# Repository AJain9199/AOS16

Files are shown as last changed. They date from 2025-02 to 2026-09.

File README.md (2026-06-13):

<!-- Improved compatibility of back to top link: See: https://github.com/othneildrew/Best-README-Template/pull/73 -->

<!--
*** Thanks for checking out the Best-README-Template. If you have a suggestion
*** that would make this better, please fork the repo and create a pull request
*** or simply open an issue with the tag "enhancement".
*** Don't forget to give the project a star!
*** Thanks again! Now go create something AMAZING! :D
-->

<!-- PROJECT SHIELDS -->
<!--
*** I'm using markdown "reference style" links for readability.
*** Reference links are enclosed in brackets [ ] instead of parentheses ( ).
*** See the bottom of this document for the declaration of the reference variables
*** for contributors-url, forks-url, etc. This is an optional, concise syntax you may use.
*** https://www.markdownguide.org/basic-syntax/#reference-style-links
-->

<!-- PROJECT LOGO -->
<br />
<div align="center">
    <a href="https://github.com/github_username/repo_name">
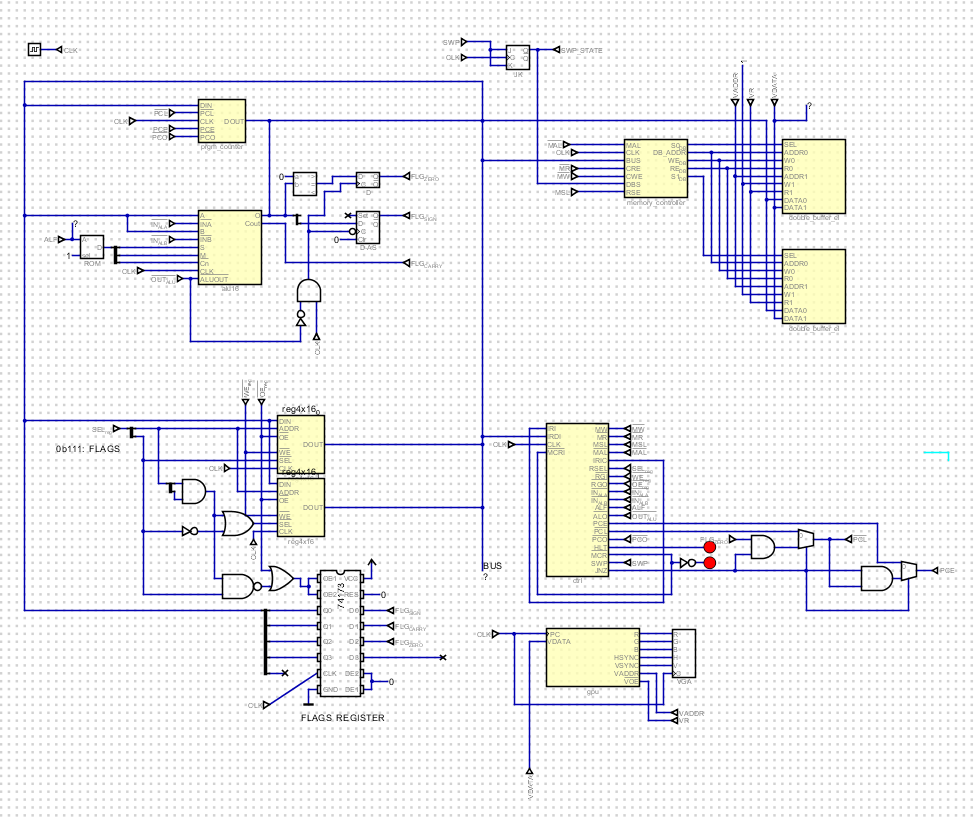
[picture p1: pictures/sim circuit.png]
    
  </a>
    <h1 align="center">AOS16</h1>
  <p align="center">
    A self-made 16-bit computer.
  </p>
</div>

<!-- TABLE OF CONTENTS -->
<details>
  <summary>Table of Contents</summary>
  <ol>
    <li>
      <a href="#about-the-project">About The Project</a>
    </li>
    <li><a href="#pictures">Pictures</a></li>
    <li><a href="#technical-details">Technical Details</a></li>
    <li><a href="#directory-structure">Directory Structure</a></li>
    <li><a href="#to-do">To-Do</a></li>
    <li><a href="#acknowledgments">Acknowledgments</a></li>
  </ol>
</details>

<!-- ABOUT THE PROJECT -->

## About The Project

AOS16 is a self-made 16-bit Reduced Instruction Set Computer (RISC) on PCBs, complete with a homebrew GPU for screen output. It is fully planned, designed and fabricated from scratch. A Turing-complete, Harvard-style computer with a completely custom architecture, at a blistering fast 10MHz.

The project is divided into smaller subsytems on PCBs, designed to interconnect via a central bus.

### Features
- 16-bit address and data buses
- Hardware double buffering with parallel CPU and GPU operation
- 10 MHz clock
- 6 general-purpose registers, a stack pointer and a flags register
- 65 Kb of general purpose RAM
- 131 Kb of framebuffer (double buffered, so 65Kb usable)
- 131 Kb of program memory

### Why?

This project was a learning effort for me. I started this project wanting to learn more about computer architectures and gain hands-on experience with electrical engineering. Also, building a computer, from scratch, is the coolest project I've seen around. Some inspiration from amazing engineers including Ben Eater and jdh were more than enough to convince me to try my hand at this project.

### How's it different?

Most homebrew computers on the internet are 8-bit computers built on breadboards.  AOS16 is novel in its capabilities, being a 16-bit computer built on PCBs with a much higher clock speed, with display support directly integrated. 

<p align="right">(<a href="#readme-top">back to top</a>)</p>

## Pictures

<!-- The animated GIFs will not be visible in the PDF! Please visit the repository on [Github](https://github.com/AJain9199/AOS16). -->

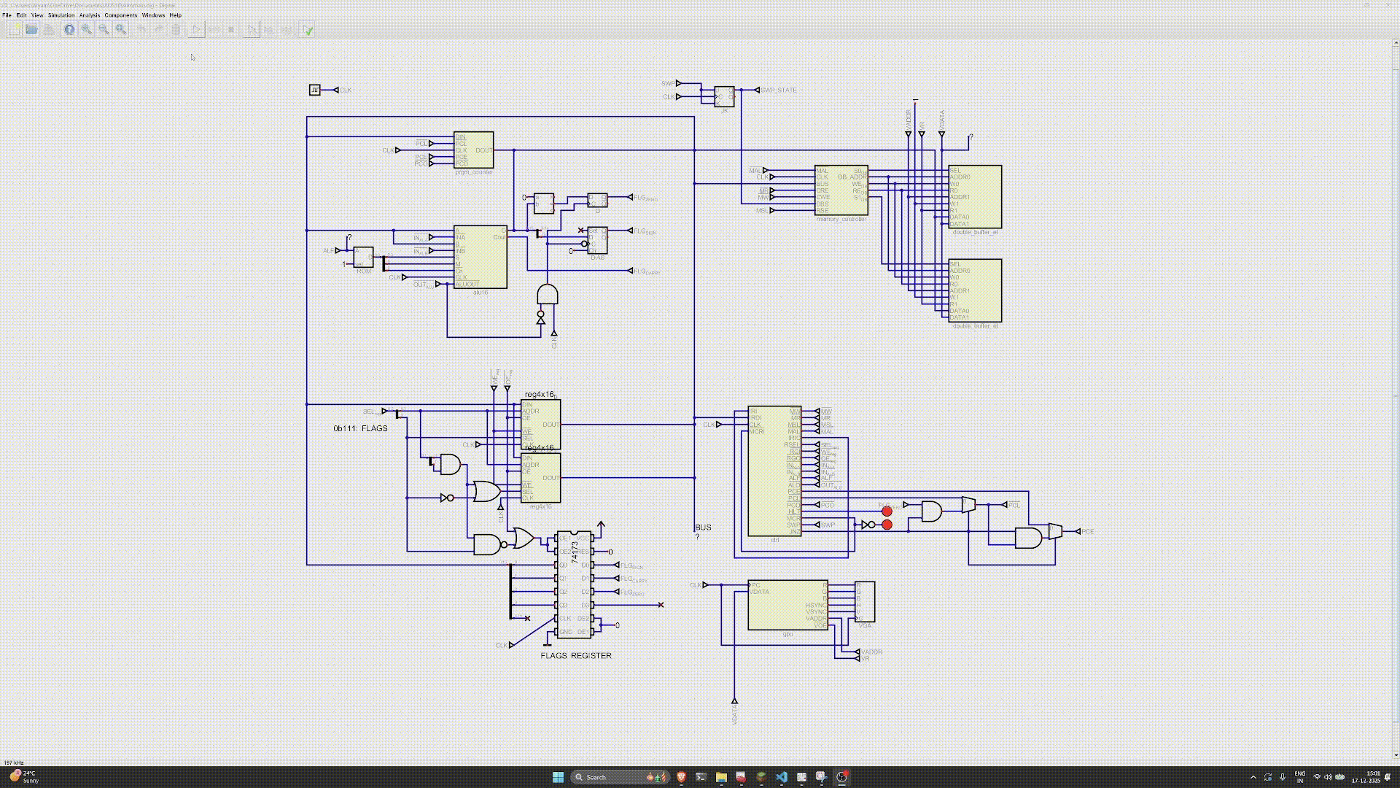
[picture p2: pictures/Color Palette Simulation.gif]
Simulation of Color Palette on Screen


<h2 align="center">
A simulation of the computer in Digital displaying the color palette on the screen
</h2>

<br>

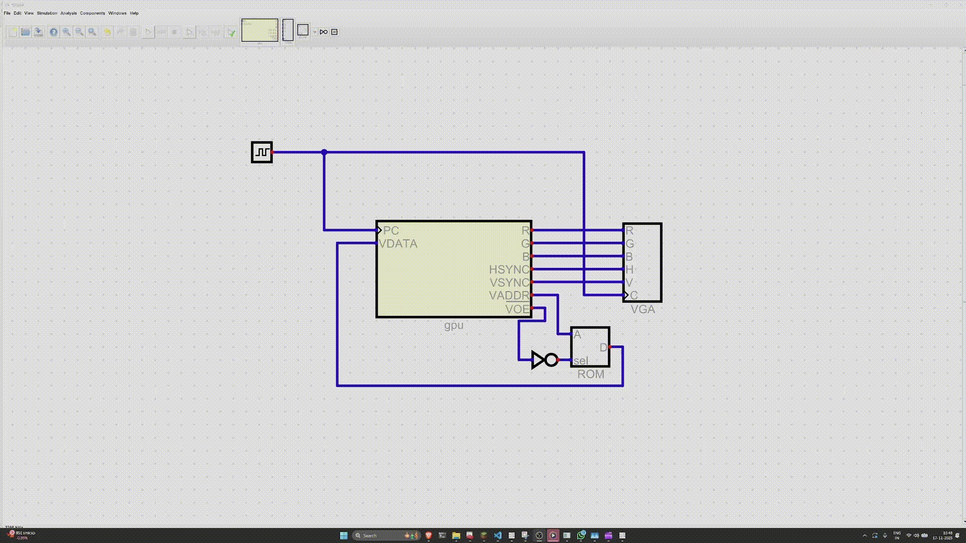
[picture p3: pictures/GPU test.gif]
A GPU Test


<h2 align="center">
    GPU displaying the pillars of creation
</h2>

<br>

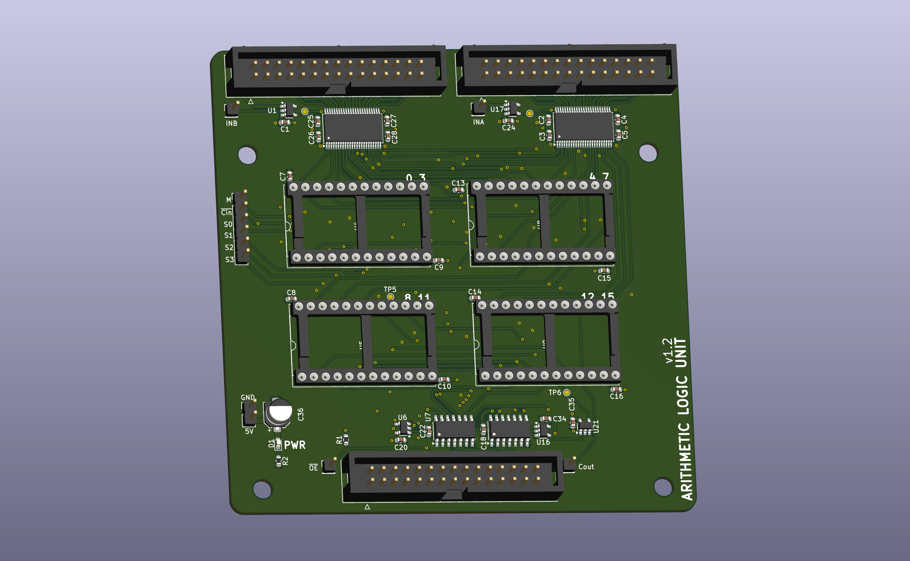
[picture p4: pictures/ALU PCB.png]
ALU PCB


<h2 align="center">
    The Arithmetic Logic Unit in KiCAD
</h2>

<br>

Logic Simulation in Digital

<h2 align="center">
    The logic simulation in Digital.
</h2>

<br>

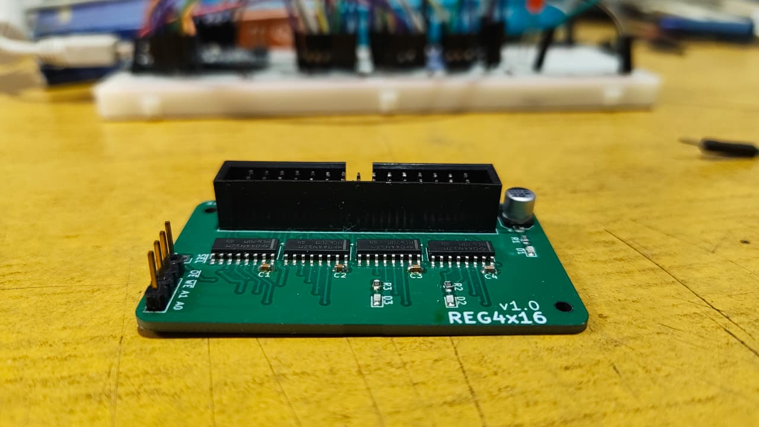
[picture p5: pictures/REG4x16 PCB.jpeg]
Fabricated Reg4x16 PCB


<h2 align="center">
    The Reg4x16 PCB 
</h2>

<br>

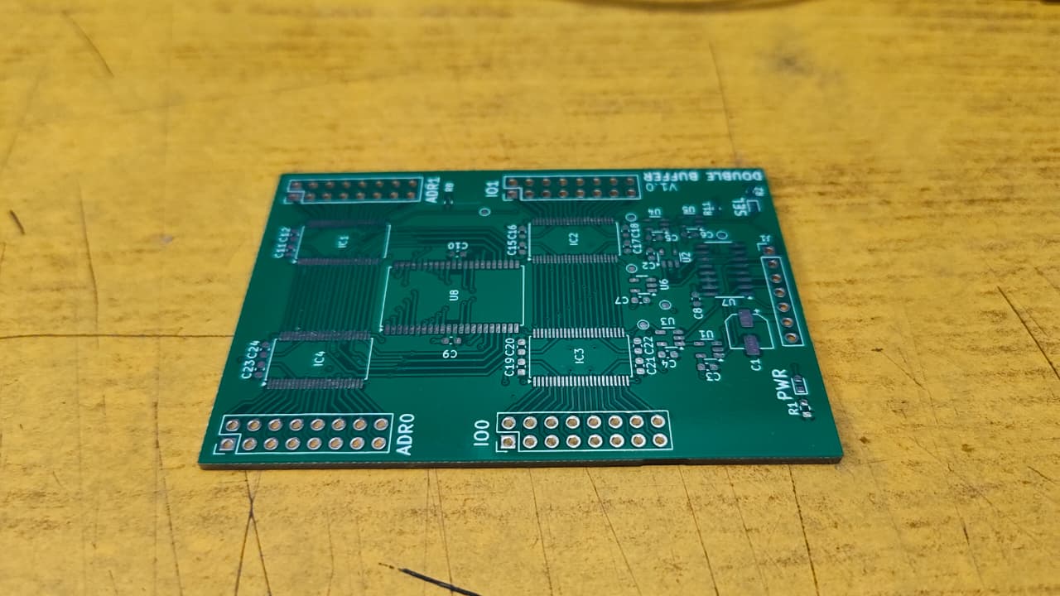
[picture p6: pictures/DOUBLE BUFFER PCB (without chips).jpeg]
Fabricated Double Buffer PCB


<h2 align="center">
    The Double Buffer PCB
</h2>

<br>

<p align="right">(<a href="#readme-top">back to top</a>)</p>

## Technical Details

Details about the design decisions, design of the instruction word, etc. can be found in the [Design Doc](AOS-16%20Design.md).

## Directory Structure

- assembler: Contains the source code for the AOS16 assembler
- sim: Logic simulation files written for Digital
- microcode: Microcode implementations written in MiLa
- tests: some basic tests for ICs and the simulation
- common: basic KiCAD schematics (registers, transceivers) which are shared across subsystems

Each of the remaining folders represents a subsystem, built on a separate PCB. Each folder will contain a KiCAD schematic and PCB file.

## To-do

Main Phases of the project:

-   [x] Finalize project parameters and design goals
-   [ ] Hardware:
    -   [x] Logic Simulation and Design
    -   [ ] PCB Design
    -   [ ] PCB Fabrication & integration
-   [x] Software:
    -   [x] Microcode (with [MiLa](https://github.com/AJain9199/MiLa))
    -   [x] Assembly language design
    -   [x] Assembler
    -   [x] ROM programming software

<br>

| Component / Phase | Logic Simulation | PCB Design | Fabrication and Integration |
| --- | --- | --- | --- |
| Double Buffer | ✅ | ✅ | ✅ |
| Memory Controller | ✅ | ✅ | ✅ |
| ALU | ✅ | ✅ | ✅ |
| Registers | ✅ | ✅ | ✅ |
| Control Unit | ✅ | ✅ |  ✅ |
| Program Counter | ✅ | ✅ |  ☐ |
| GPU | ✅ | ✅ | ☐ |
| Main Data Bus | ✅ | ✅ | ☐ |
| **Phase Completed** | ✅ | ✅ | ☐ |

<p align="right">(<a href="#readme-top">back to top</a>)</p>

<!-- ACKNOWLEDGMENTS -->
## Acknowledgments

-   [Ben Eater](https://www.youtube.com/@BenEater) for his excellent series on the breadboard computer
-   [jdh](https://www.youtube.com/@jdh) for the inspiration
-   The Elements of Computing Systems and the accompanying [Nand2Tetris](https://www.nand2tetris.org/) course by Shimon Schocken and Noam Nisan
-   [r/homebrewcomputer](https://www.reddit.com/r/homebrewcomputer/) and [r/PrintedCircuitBoard](https://www.reddit.com/r/PrintedCircuitBoard/) commmunities for PCB reviews and design checks
-   [Digital](https://github.com/hneemann/Digital), the logic simulator

<p align="right">(<a href="#readme-top">back to top</a>)</p>

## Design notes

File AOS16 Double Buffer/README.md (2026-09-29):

# Double Buffer
The double buffer is one of the most complicated PCBs in the project. It serves the important function of facilitating data transfer between the CPU and GPU.

```mermaid
flowchart LR
    ADDR0[\"ADDR0"\]
    IO0[\"IO0"\]
    buf1["Buffer"]
    buf2{{"Transceiver"}}
    sram["SRAM"]
    ADDR1[/"ADDR1"/]
    IO1[/"IO1"/]
    buf3["Buffer"]
    buf4{{"Transceiver"}}
    ctrl["`Control Circuit`"]
    nr0(("nR0"))
    nw0(("nW0"))
    nr1(("nR1"))
    nw1(("nW1"))
    swp(("SWP"))
    ADDR0 --> buf1
    IO0 --> buf2
    buf1 --> sram
    buf2 --> sram
    ADDR1 --> buf3
    IO1 --> buf4
    buf3 --> sram
    buf4 --> sram
    nr0 --> ctrl
    nw0 --> ctrl
    nr1 --> ctrl
    nw1 --> ctrl
    swp --> ctrl
    ctrl -->|"direction, output enable"| buf2
    ctrl -->|"direction, output enable"| buf4
    ctrl -->|"output enable"| buf1
    ctrl -->|"output enable"| buf3
    linkStyle 14 stroke:#aaaaaa,color:#888888
    %% mermaid-flow:pos ADDR0=292,326 IO0=295,462 buf1=482,329 buf2=482,462 sram=693,404 ADDR1=1056,323 IO1=1059,465 buf3=887,323 buf4=884,465 ctrl=689,899 nr0=302,1107 nw0=302,977 nr1=302,847 nw1=302,717 swp=302,587
```

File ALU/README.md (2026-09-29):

# Arithmetic Logic Unit
The Arithmetic Logic Unit is one of the the first PCBs I designed and built as part of the project. It is essentially a wrapper for the 74LS181 ICs, 4 of them handling each of the 4 nibbles, with additional circuitry to manage the IO and carry generation for each of the 4 chips.

ALU PCB

```mermaid
flowchart LR
	porta@{ shape: lean-r, label: "PORT A"}
	latcha["`Latch A`"]
	porta --> latcha
	ina((INA))
	ina --> latcha
	
	portb@{ shape: lean-r, label: "PORT B"}
	latchb["`Latch B`"]
	portb --> latchb
	inb((INB))
	inb --> latchb
	
	subgraph alu [Arithmetic Unit]
		aluchip1@{ shape: subproc, label: "74LS181 A" }
		aluchip2@{ shape: subproc, label: "74LS181 B" }
		aluchip3@{ shape: subproc, label: "74LS181 C" }
		aluchip4@{ shape: subproc, label: "74LS181 D" }
		
		carrygen["`Carry Generator`"]
		
		carrygen --> aluchip1
		carrygen --> aluchip2
		carrygen --> aluchip3
		carrygen --> aluchip4
	end
	
	latcha --> alu
	latchb --> alu
	
	buffer@{shape: tri, label: "Tri-State Buffer"}
	noe((nOE))
	noe --> buffer
	
	alu --> buffer --> outport
	carryout((nCo))
	alu --> carryout
	
	alus(["`S[0..3]`"]) --> alu
	m((M)) --> alu
	cin((nCin)) --> alu
	
	outport@{ shape: lean-r, label: "OUTPUT"}
```

## Carry Generation

Since each 74LS181 chip only handles 4 bits, 4 of these chips need to be used together. Instead of cascading them using the built-in carry outputs, I used full look-ahead carry generation which is more than 2x faster ([sn54s181](sn54s181.pdf)) (realistically both are fine at the speeds this works at, this is simply future/idiot proofing) But I couldn't find the carry generation chip, the 182, so I replicated the internal circuit using discrete (A)HCT gates ([sn54s182](sn54s182.pdf)).

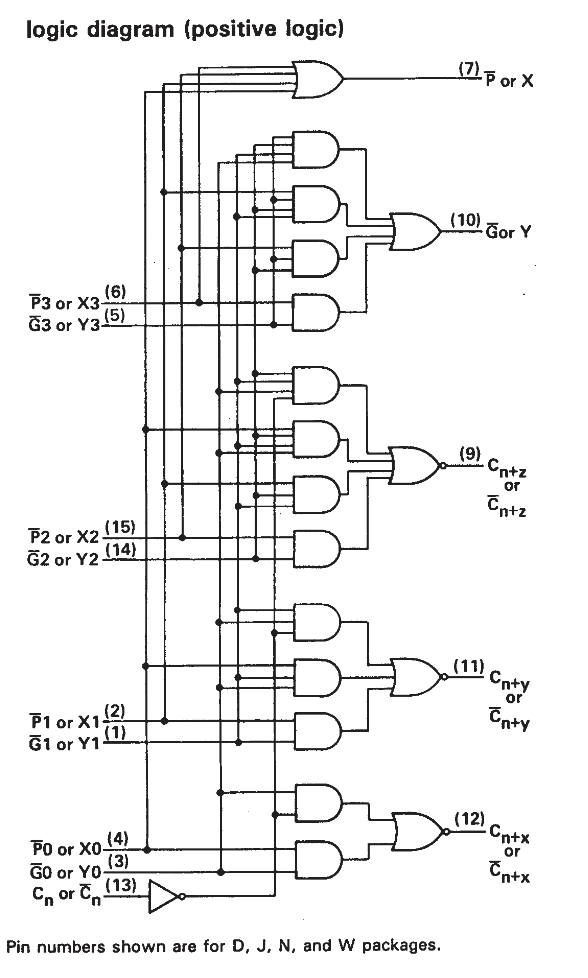
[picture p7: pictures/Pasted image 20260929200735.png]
Circuit diagram


Since I wasn't sure if this will work, I added test pads on the cascade carry outputs and inputs so they could be used as a contingency.

## Latches
The 181s need both A and B inputs driven at the same time to function correctly. Since they ultimately need to be driven by the same bus, the inputs are latched using separate signals which drive the physical inputs. I considered adding a second bus only to drive port B, but the added complexity was not worth the benefit of saving 1-2 microcode instructions and 2 control signals.

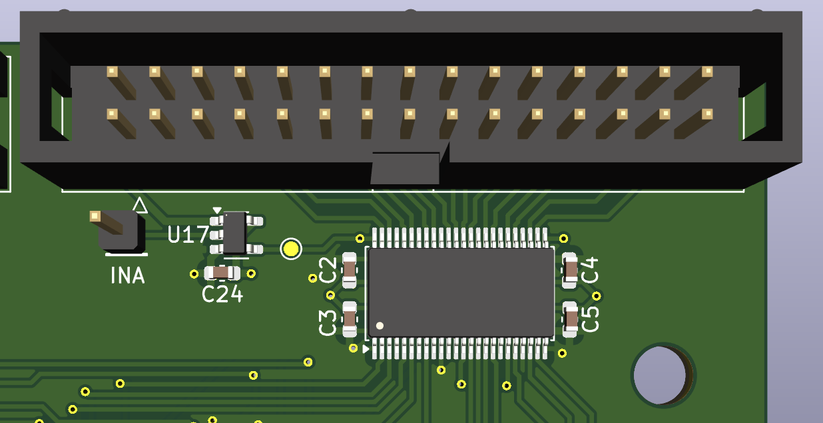
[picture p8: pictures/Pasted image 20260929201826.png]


Inputs are latched at the rising edge. The AHCT16374's ([sn74ahct16374](sn74ahct16374.pdf)) are asynchronous, so the latching input is and'ed with the clock to make them "synchronous."

## Iterations
- v1.0: The control signals on the 16374 were routed wrong due to a schematic symbol mismatch
- v1.1: The 16374 was routed wrong (again)
- v1.2: Final

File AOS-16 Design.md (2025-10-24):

# AOS-16

## Features

-   16-bit data and address buses
-   Harvard architecture
-   GPU hardware double bufferring
-   Memory Mapped IO

## Instruction

-   5-bit Opcode for a total of 32 distinct instructions
-   Direction Bit: Determines whether contents move from operand 1 to 2 (0) or operand 2 to 1 (1)
-   Reg: 3-bit register select
-   M/C/Reg: 2 bits to control whether operand is an immediate, immediate pointer, register pointer or simply a register, for a total of 5 bits.
-   If the 'C' flag is set, the instruction must be 4 bytes long. Other instructions are 2 bytes long.

### Instruction Set

-   00000: ADD reg/m, m/imm16/reg
-   00001: SUB reg/m, m/imm16/reg
-   00010: AND reg/m, m/imm16/reg
-   00011: NAND reg/m, m/imm16/reg
-   00100: OR reg/m, m/imm16/reg
-   00101: NOR reg/m, m/imm16/reg
-   00110: XOR reg/m, m/imm16/reg
-   00111: NEG reg/m, m/imm16/reg
-   01000: NOT reg/m, m/imm16/reg
-   01001: SHL reg/m
-   01010: INC reg/m
-   01011: DEC reg/m
-   01100: CMP reg/m, m/imm16/reg
-   01101: MOV reg/m, m/imm16/reg
-   01110: PUSH m/imm16/reg
-   01111: POP m/reg
-   10000: SWP
-   10001: JMP imm16/reg
-   10010: JNZ imm16/reg
-   10011: JEQ imm16/reg
-   10100: JLT imm16/reg
-   10101: JLE imm16/reg
-   10110: JGT imm16/reg
-   10111: JGE imm16/reg
-   11000: HLT
-   11001: CALL imm16/reg/m
-   11010: RET
-   11011: INT imm4
-   11100: IRET
-   11101 - 11110: UNALLOCATED
-   11111: NOP (Data is all high in EEPROM upon erase)

## Registers

-   000: AX
-   001: BX
-   010: CX
-   011: DX
-   100: EX
-   101: FX
-   110: SP: Stack Pointer
-   111: STATUS

### STATUS REGISTER

The bits in the status register, from LSB to MSB:

-   0: GPU READY
-   1: ZF
-   2: CF
-   3: SF
-   4-15: unallocated

## Memory Map

0x0000...0x7FF7: GP RAM
0x7FF8...0x7FFF: MEMORY MAPPED IO
0x8FFF...0xFFFF: FRAMEBUFFER

## Control Word

-   0: MI: Memory Write
-   1: MO: Memory Out
-   2: MSL: Memory Select (0 for RAM, 1 for ROM)
-   3: MAI: Memory Address In
-   4: IRI: Instruction Register In
-   5...7: RSA[3]: Register Select for Bus A (see REGISTERS)
-   8: RGI: Register In
-   9: RGO: Register Out
-   10: AAI: ALU A In
-   11: ABI: ALU B In
-   12...15: ALF[4]: ALU Opcode
-   16: /ALO: ALU Out
-   17: PCE: Program Counter Enable
-   18: /PCL: Program Counter Load/Jump
-   19: PCO: Program Counter Out
-   20: HLT: Global Halt
-   21: MCR: Microcode Reset
-   22: SWAP: Swap the double buffer selection

## Application Binary Interface (ABI)
Functions are called using the `call` instruction. The current instruction pointer is pushed to the stack. Arguments to the function are pushed onto the stack in order. Results are placed in the 'dx' register.

`ret` restores the instruction pointer to the last word on the stack.

## GPU
VGA Timing Mode: VESA 1280x1024 @60Hz\
Resolution: 160x128 (5:4 aspect ratio)\
Clock: 13.5MHz

### VGA Timing
Horizontal Timing

| Scanline Part | Pixels | Pixel Counter |
|---|---| --- |
| Visible Area  | 160 | 160 (0b10100000) |
| Front porch | 6 | 166 (0b10100110) |
| Sync Pulse | 14 | 180 (0b10110100) |
| Back porch | 31 | 211 (0b11010011) |
| Whole Line | 211 | |

 Vertical Timing (Every pixel is repeated 8 times in vertical direction to achieve 128 lines)

| Frame part | Lines | Line Counter | 
| --- | ----- | --- |
| Visible Area | 1024 | 1024 (0b0100 0000 0000) |
| Front porch | 1 | 1025 (0b0100 0000 0001) |
| Sync Pulse | 3| 1028 (0b0100 0000 0100)|
| Back Porch | 38 | 1066 (0b0100 0010 1010) |

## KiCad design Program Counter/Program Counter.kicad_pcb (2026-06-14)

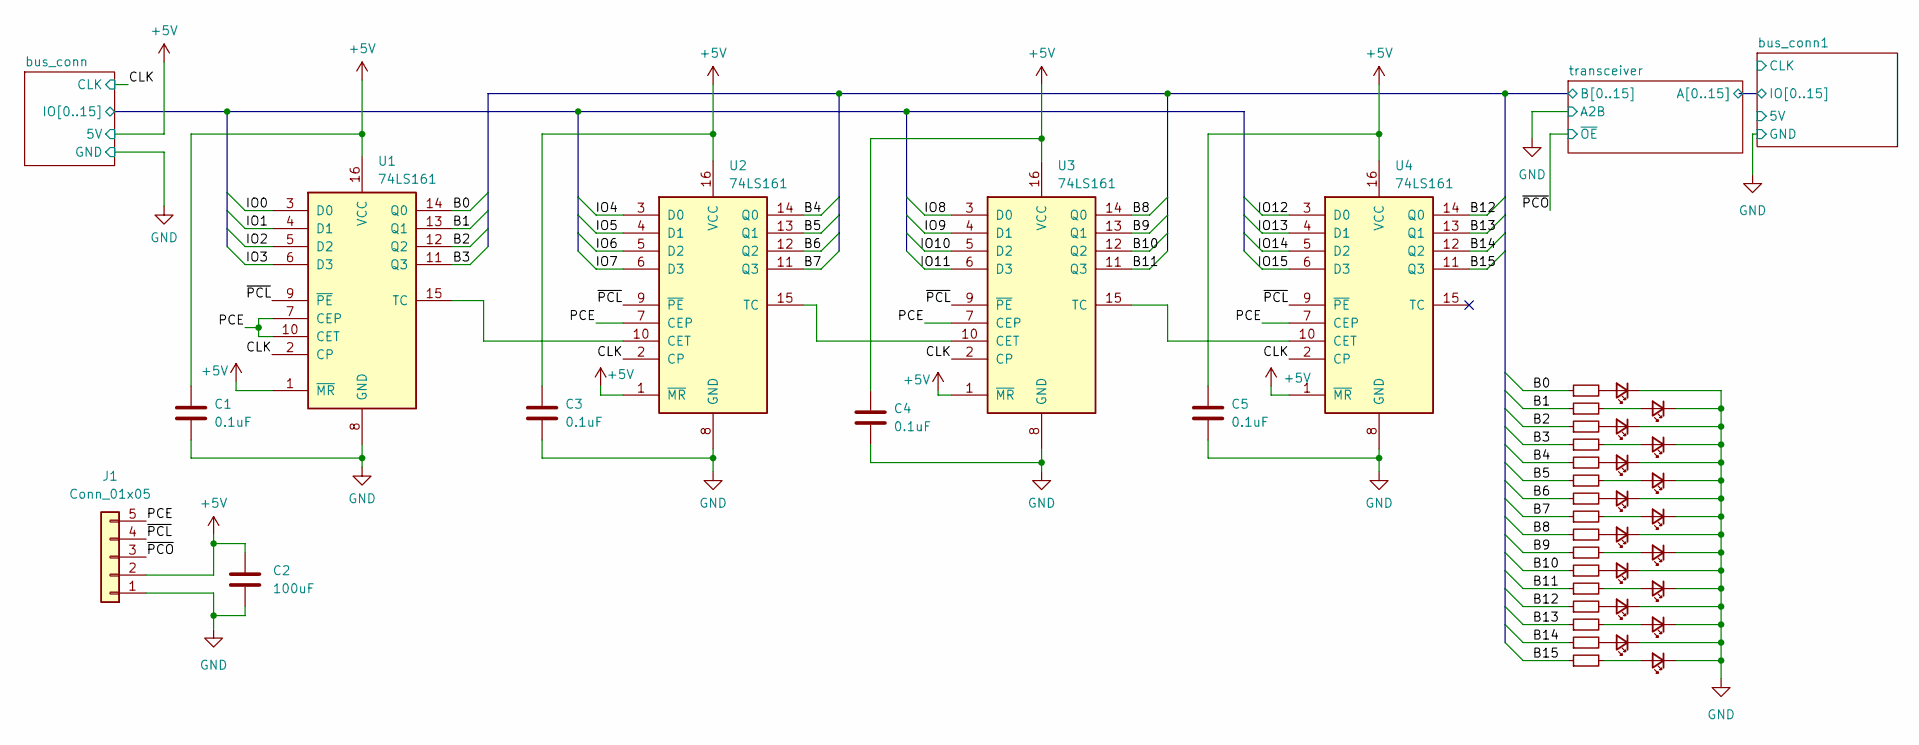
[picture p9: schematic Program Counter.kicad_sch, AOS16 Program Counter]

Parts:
C1, C3, C4, C5: 0.1uF; C_0603_1608Metric
C2: 100uF; CP_Elec_5x5.3
D1, D2, D3, D4, D5, D6, D7, D8, D9, D10, D11, D12, D13, D14, D15, D16: LED_Small; LED_0603_1608Metric
J1: Conn_01x05; PinHeader_1x05_P2.54mm_Vertical
R2, R3, R4, R5, R6, R7, R8, R9, R10, R11, R12, R13, R14, R15, R16, R17: 220; R_0603_1608Metric
U1, U2, U3, U4: 74LS161; SOIC-16_4.55x10.3mm_P1.27mm

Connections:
/CLK: U1.2 (CP), U2.2 (CP), U3.2 (CP), U4.2 (CP); also elsewhere on the board
/PCE: J1.5, U1.7 (CEP), U1.10 (CET), U2.7 (CEP), U3.7 (CEP), U4.7 (CEP)
/bus_conn/IO0: U1.3 (D0); also elsewhere on the board
/bus_conn/IO1: U1.4 (D1); also elsewhere on the board
/bus_conn/IO2: U1.5 (D2); also elsewhere on the board
/bus_conn/IO3: U1.6 (D3); also elsewhere on the board
/bus_conn/IO4: U2.3 (D0); also elsewhere on the board
/bus_conn/IO5: U2.4 (D1); also elsewhere on the board
/bus_conn/IO6: U2.5 (D2); also elsewhere on the board
/bus_conn/IO7: U2.6 (D3); also elsewhere on the board
/bus_conn/IO8: U3.3 (D0); also elsewhere on the board
/bus_conn/IO9: U3.4 (D1); also elsewhere on the board
/bus_conn/IO10: U3.5 (D2); also elsewhere on the board
/bus_conn/IO11: U3.6 (D3); also elsewhere on the board
/bus_conn/IO12: U4.3 (D0); also elsewhere on the board
/bus_conn/IO13: U4.4 (D1); also elsewhere on the board
/bus_conn/IO14: U4.5 (D2); also elsewhere on the board
/bus_conn/IO15: U4.6 (D3); also elsewhere on the board
/transceiver/B0: R2.1, U1.14 (Q0); also elsewhere on the board
/transceiver/B1: R3.1, U1.13 (Q1); also elsewhere on the board
/transceiver/B2: R4.1, U1.12 (Q2); also elsewhere on the board
/transceiver/B3: R5.1, U1.11 (Q3); also elsewhere on the board
/transceiver/B4: R6.1, U2.14 (Q0); also elsewhere on the board
/transceiver/B5: R7.1, U2.13 (Q1); also elsewhere on the board
/transceiver/B7: R9.1, U2.11 (Q3); also elsewhere on the board
/transceiver/B8: R10.1, U3.14 (Q0); also elsewhere on the board
/transceiver/B9: R11.1, U3.13 (Q1); also elsewhere on the board
/transceiver/B10: R12.1, U3.12 (Q2); also elsewhere on the board
/transceiver/B11: R13.1, U3.11 (Q3); also elsewhere on the board
/transceiver/B12: R14.1, U4.14 (Q0); also elsewhere on the board
/transceiver/B13: R15.1, U4.13 (Q1); also elsewhere on the board
/transceiver/B14: R16.1, U4.12 (Q2); also elsewhere on the board
/transceiver/B15: R17.1, U4.11 (Q3); also elsewhere on the board
/~PCL: J1.4, U1.9 (~PE), U2.9 (~PE), U3.9 (~PE), U4.9 (~PE)
GND: C1.2, C2.2, C3.2, C4.2, C5.2, D1.1 (K), D2.1 (K), D3.1 (K), D4.1 (K), D5.1 (K), D6.1 (K), D7.1 (K), D8.1 (K), D9.1 (K), D10.1 (K), D11.1 (K), D12.1 (K), D13.1 (K), D14.1 (K), D15.1 (K), D16.1 (K), J1.1, U1.8 (GND), U2.8 (GND), U3.8 (GND), U4.8 (GND); also elsewhere on the board
unnamed: D1.2 (A), R2.2
unnamed: D2.2 (A), R4.2
unnamed: D3.2 (A), R6.2
unnamed: D5.2 (A), R10.2
unnamed: D6.2 (A), R12.2
unnamed: D7.2 (A), R14.2
unnamed: D8.2 (A), R16.2
unnamed: D9.2 (A), R3.2
unnamed: D10.2 (A), R5.2
unnamed: D11.2 (A), R7.2
unnamed: D12.2 (A), R9.2
unnamed: D13.2 (A), R11.2
unnamed: D14.2 (A), R13.2
unnamed: D15.2 (A), R15.2
unnamed: D16.2 (A), R17.2
unnamed: U1.15 (TC), U2.10 (CET)
unnamed: U2.15 (TC), U3.10 (CET)
unnamed: U3.15 (TC), U4.10 (CET)

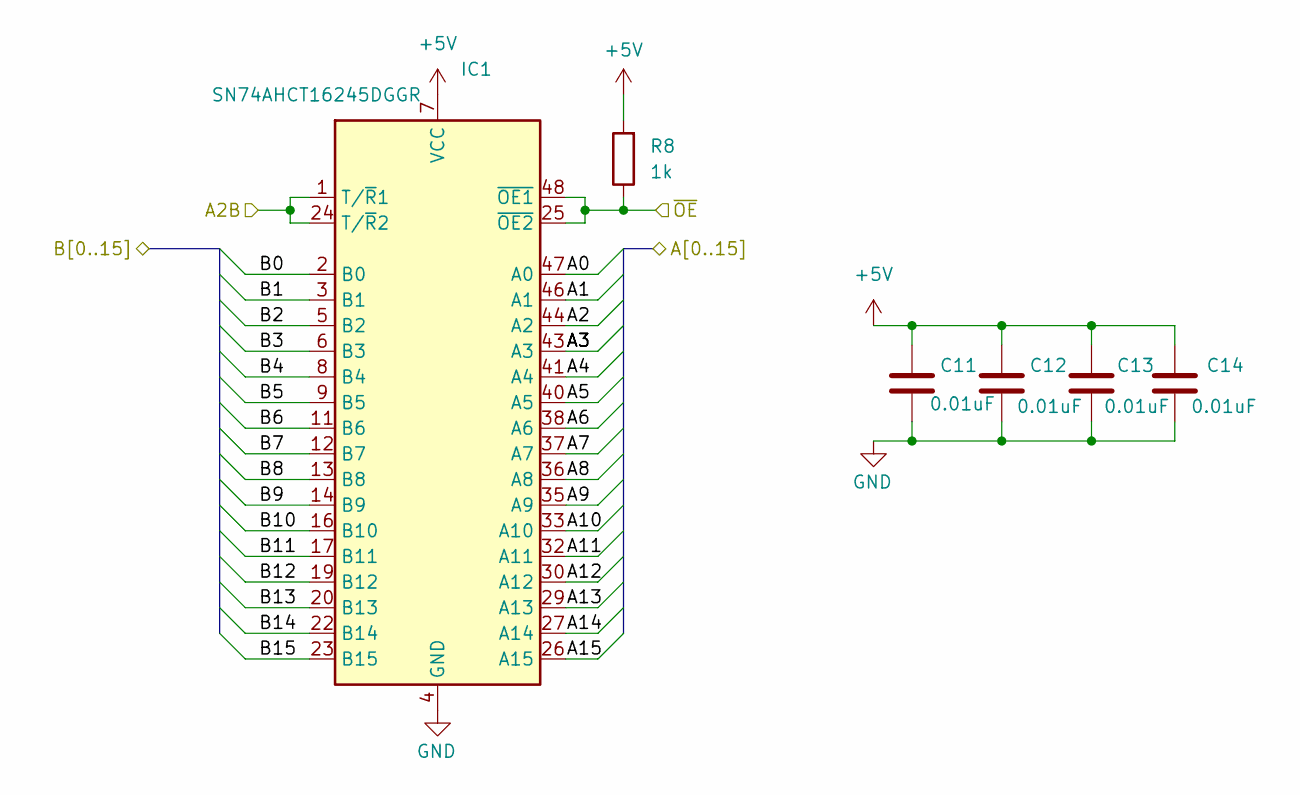
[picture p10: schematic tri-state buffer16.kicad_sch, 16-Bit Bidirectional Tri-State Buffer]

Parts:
C11, C12, C13, C14: 0.01uF; C_0603_1608Metric
IC1: SN74AHCT16245DGGR; TSSOP-48_6.1x12.5mm_P0.5mm
R8: 1k; R_0603_1608Metric

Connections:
/bus_conn1/IO0: IC1.47 (A0); also elsewhere on the board
/bus_conn1/IO1: IC1.46 (A1); also elsewhere on the board
/bus_conn1/IO2: IC1.44 (A2); also elsewhere on the board
/bus_conn1/IO3: IC1.43 (A3); also elsewhere on the board
/bus_conn1/IO4: IC1.41 (A4); also elsewhere on the board
/bus_conn1/IO5: IC1.40 (A5); also elsewhere on the board
/bus_conn1/IO6: IC1.38 (A6); also elsewhere on the board
/bus_conn1/IO7: IC1.37 (A7); also elsewhere on the board
/bus_conn1/IO8: IC1.36 (A8); also elsewhere on the board
/bus_conn1/IO9: IC1.35 (A9); also elsewhere on the board
/bus_conn1/IO10: IC1.33 (A10); also elsewhere on the board
/bus_conn1/IO11: IC1.32 (A11); also elsewhere on the board
/bus_conn1/IO12: IC1.30 (A12); also elsewhere on the board
/bus_conn1/IO13: IC1.29 (A13); also elsewhere on the board
/bus_conn1/IO14: IC1.27 (A14); also elsewhere on the board
/bus_conn1/IO15: IC1.26 (A15); also elsewhere on the board
/transceiver/B0: IC1.2 (B0); also elsewhere on the board
/transceiver/B1: IC1.3 (B1); also elsewhere on the board
/transceiver/B2: IC1.5 (B2); also elsewhere on the board
/transceiver/B3: IC1.6 (B3); also elsewhere on the board
/transceiver/B4: IC1.8 (B4); also elsewhere on the board
/transceiver/B5: IC1.9 (B5); also elsewhere on the board
/transceiver/B7: IC1.12 (B7); also elsewhere on the board
/transceiver/B8: IC1.13 (B8); also elsewhere on the board
/transceiver/B9: IC1.14 (B9); also elsewhere on the board
/transceiver/B10: IC1.16 (B10); also elsewhere on the board
/transceiver/B11: IC1.17 (B11); also elsewhere on the board
/transceiver/B12: IC1.19 (B12); also elsewhere on the board
/transceiver/B13: IC1.20 (B13); also elsewhere on the board
/transceiver/B14: IC1.22 (B14); also elsewhere on the board
/transceiver/B15: IC1.23 (B15); also elsewhere on the board
GND: C11.2, C12.2, C13.2, C14.2, IC1.1 (T/~R1), IC1.4 (GND), IC1.10 (GND), IC1.15 (GND), IC1.21 (GND), IC1.24 (T/~R2), IC1.28 (GND), IC1.34 (GND), IC1.39 (GND), IC1.45 (GND); also elsewhere on the board

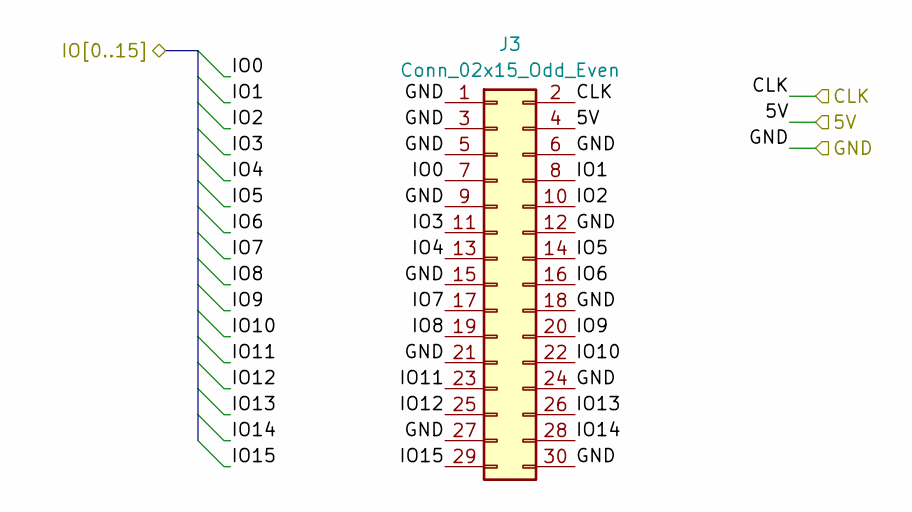
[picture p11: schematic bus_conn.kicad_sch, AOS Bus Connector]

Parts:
J3: Conn_02x15_Odd_Even; IDC-Header_2x15_P2.54mm_Vertical

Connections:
/bus_conn1/5V: J3.4
/bus_conn1/CLK: J3.2
/bus_conn1/IO0: J3.7; also elsewhere on the board
/bus_conn1/IO1: J3.8; also elsewhere on the board
/bus_conn1/IO2: J3.10; also elsewhere on the board
/bus_conn1/IO3: J3.11; also elsewhere on the board
/bus_conn1/IO4: J3.13; also elsewhere on the board
/bus_conn1/IO5: J3.14; also elsewhere on the board
/bus_conn1/IO6: J3.16; also elsewhere on the board
/bus_conn1/IO7: J3.17; also elsewhere on the board
/bus_conn1/IO8: J3.19; also elsewhere on the board
/bus_conn1/IO9: J3.20; also elsewhere on the board
/bus_conn1/IO10: J3.22; also elsewhere on the board
/bus_conn1/IO11: J3.23; also elsewhere on the board
/bus_conn1/IO12: J3.25; also elsewhere on the board
/bus_conn1/IO13: J3.26; also elsewhere on the board
/bus_conn1/IO14: J3.28; also elsewhere on the board
/bus_conn1/IO15: J3.29; also elsewhere on the board
GND: J3.1, J3.3, J3.5, J3.6, J3.9, J3.12, J3.15, J3.18, J3.21, J3.24, J3.27, J3.30; also elsewhere on the board

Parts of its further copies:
J2: Conn_02x15_Odd_Even; IDC-Header_2x15_P2.54mm_Vertical

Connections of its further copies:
/CLK: J2.2; also elsewhere on the board
/bus_conn/IO0: J2.7; also elsewhere on the board
/bus_conn/IO1: J2.8; also elsewhere on the board
/bus_conn/IO2: J2.10; also elsewhere on the board
/bus_conn/IO3: J2.11; also elsewhere on the board
/bus_conn/IO4: J2.13; also elsewhere on the board
/bus_conn/IO5: J2.14; also elsewhere on the board
/bus_conn/IO6: J2.16; also elsewhere on the board
/bus_conn/IO7: J2.17; also elsewhere on the board
/bus_conn/IO8: J2.19; also elsewhere on the board
/bus_conn/IO9: J2.20; also elsewhere on the board
/bus_conn/IO10: J2.22; also elsewhere on the board
/bus_conn/IO11: J2.23; also elsewhere on the board
/bus_conn/IO12: J2.25; also elsewhere on the board
/bus_conn/IO13: J2.26; also elsewhere on the board
/bus_conn/IO14: J2.28; also elsewhere on the board
/bus_conn/IO15: J2.29; also elsewhere on the board
GND: J2.1, J2.3, J2.5, J2.6, J2.9, J2.12, J2.15, J2.18, J2.21, J2.24, J2.27, J2.30; also elsewhere on the board

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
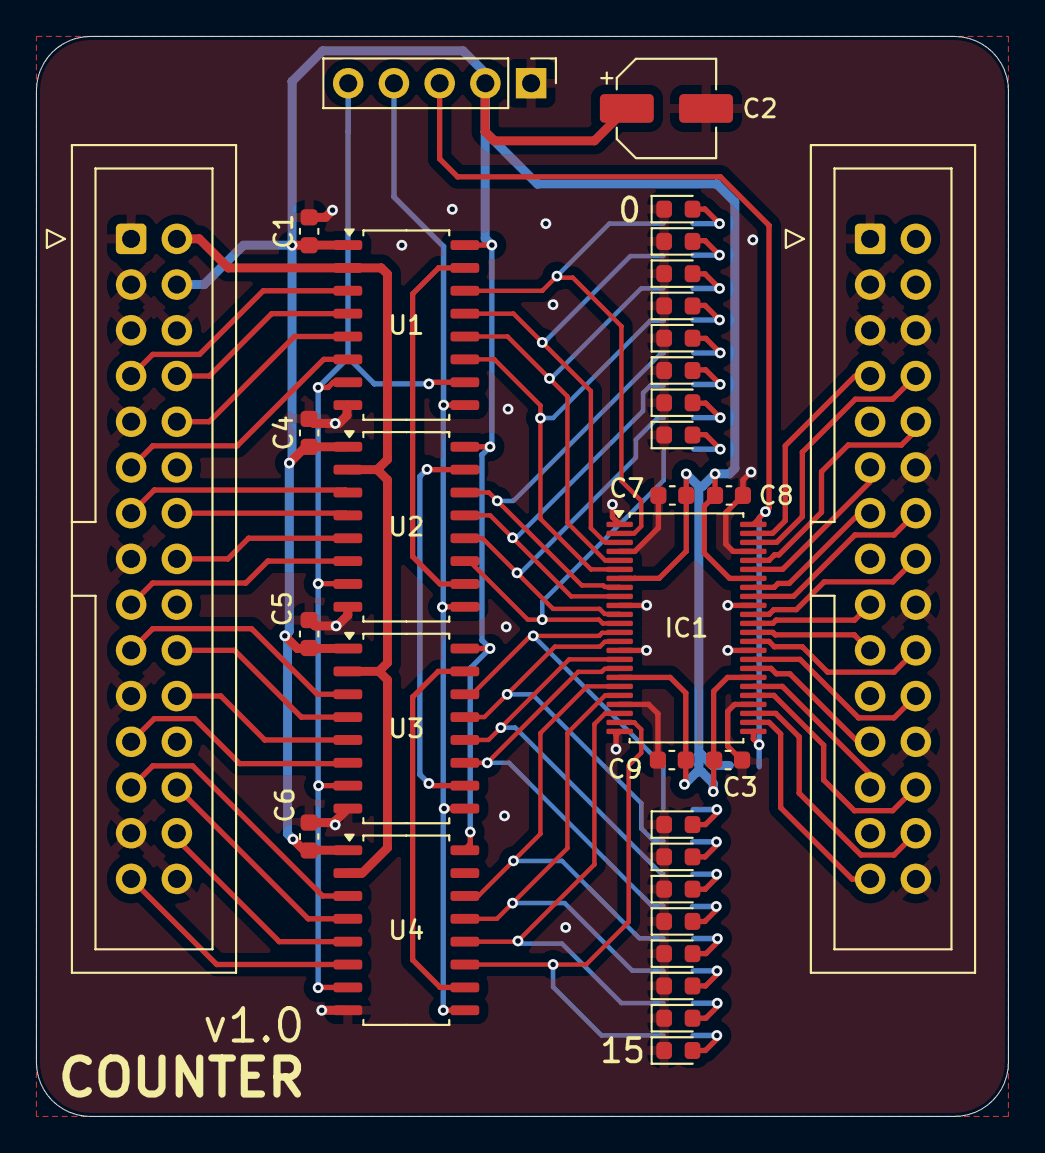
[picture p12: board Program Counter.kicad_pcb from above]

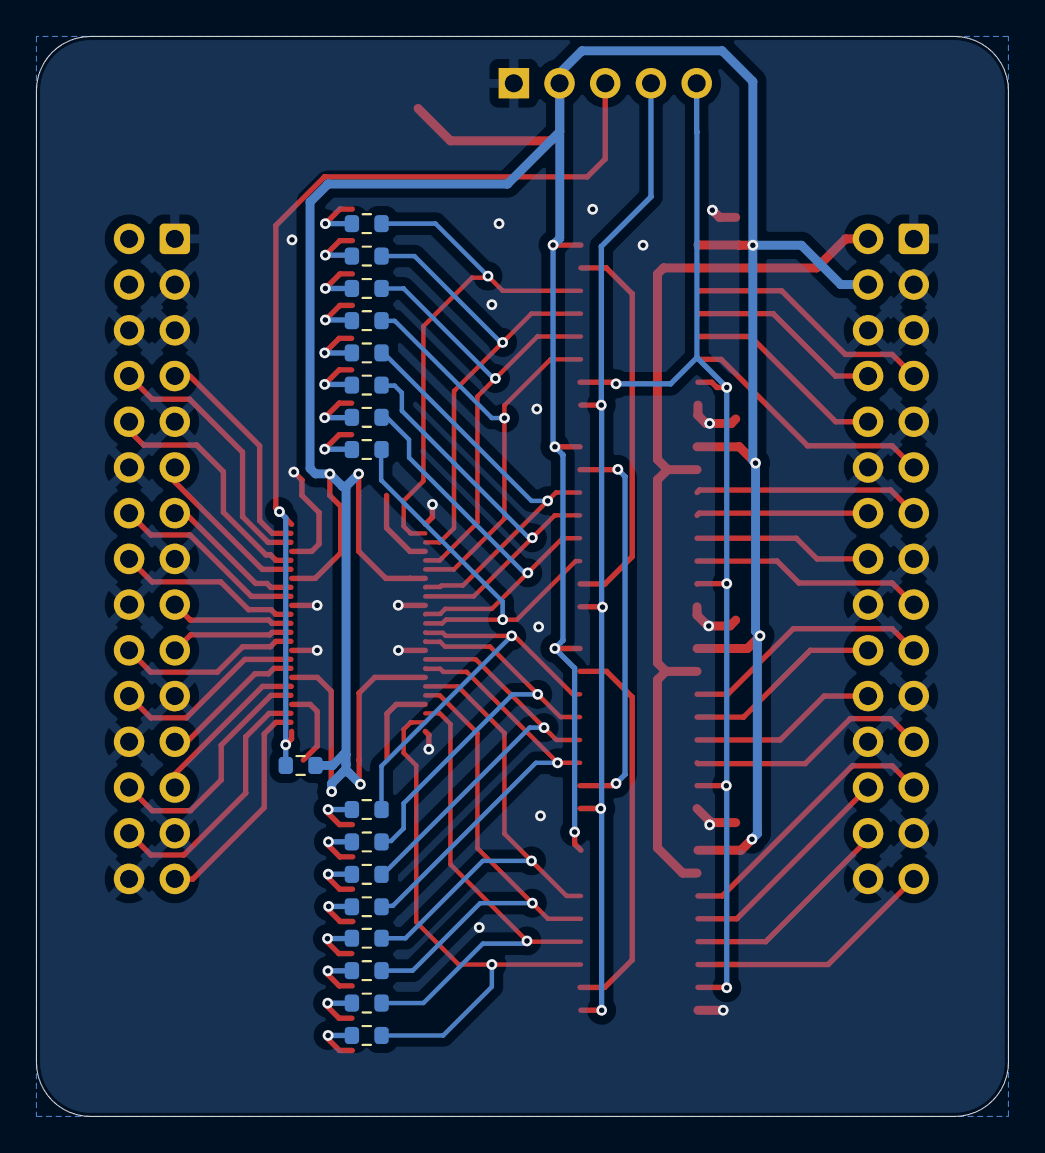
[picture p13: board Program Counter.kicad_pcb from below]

Board: 2 copper layers, 54.0 x 60.0 mm, 50 parts (17 on the bottom side), 73 nets.

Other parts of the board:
C6, C7, C8, C9: 0.01uF; C_0603_1608Metric
R18: 1k; R_0603_1608Metric

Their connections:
GND: C6.2, C7.2, C8.2, C9.2; also elsewhere on the board

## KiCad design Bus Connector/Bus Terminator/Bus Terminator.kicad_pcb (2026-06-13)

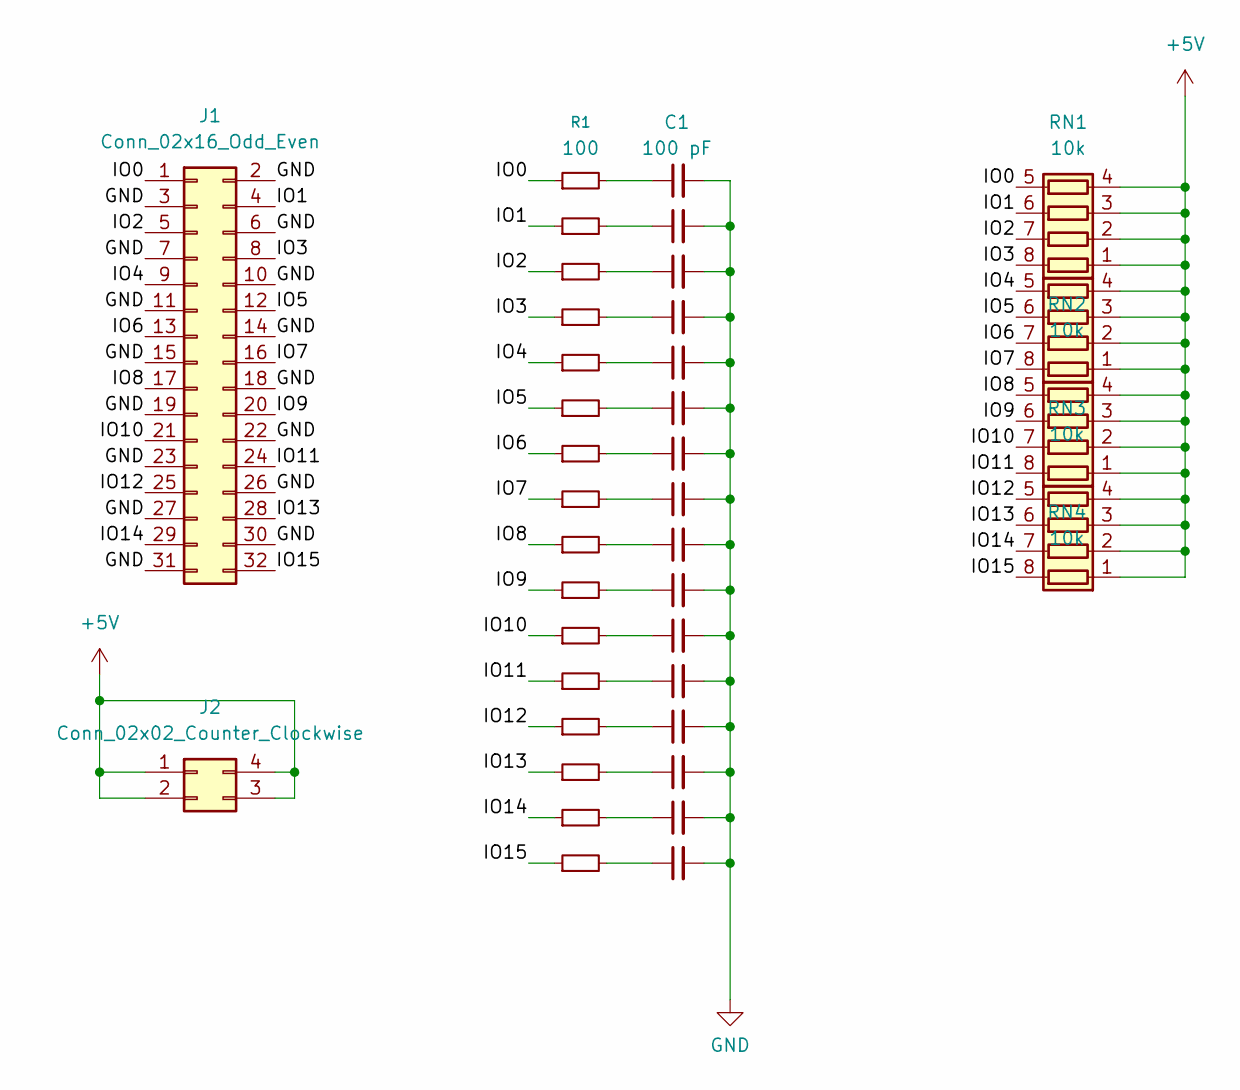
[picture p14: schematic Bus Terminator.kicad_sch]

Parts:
C1, C2, C3, C4, C5, C6, C7, C8, C9, C10, C11, C12, C13, C14, C15, C16: 100 pF; C_0603_1608Metric
J1: Conn_02x16_Odd_Even; PinHeader_2x16_P2.54mm_Horizontal
J2: Conn_02x02_Counter_Clockwise; PinHeader_2x02_P2.54mm_Horizontal
R1, R2, R3, R4, R5, R6, R7, R8, R9, R10, R11, R12, R13, R14, R15, R16: 100; R_0603_1608Metric
RN1, RN2, RN3, RN4: 10k; R_Array_Convex_4x1206

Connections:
+5V: J2.1, J2.2, J2.3, J2.4, RN1.1 (R1.1), RN1.2 (R2.1), RN1.3 (R3.1), RN1.4 (R4.1), RN2.1 (R1.1), RN2.2 (R2.1), RN2.3 (R3.1), RN2.4 (R4.1), RN3.1 (R1.1), RN3.2 (R2.1), RN3.3 (R3.1), RN3.4 (R4.1), RN4.1 (R1.1), RN4.2 (R2.1), RN4.3 (R3.1), RN4.4 (R4.1)
/IO0: J1.1, R1.1, RN1.5 (R4.2)
/IO1: J1.4, R2.1, RN1.6 (R3.2)
/IO2: J1.5, R3.1, RN1.7 (R2.2)
/IO3: J1.8, R4.1, RN1.8 (R1.2)
/IO4: J1.9, R5.1, RN2.5 (R4.2)
/IO5: J1.12, R6.1, RN2.6 (R3.2)
/IO6: J1.13, R7.1, RN2.7 (R2.2)
/IO7: J1.16, R8.1, RN2.8 (R1.2)
/IO8: J1.17, R9.1, RN3.5 (R4.2)
/IO9: J1.20, R10.1, RN3.6 (R3.2)
/IO10: J1.21, R11.1, RN3.7 (R2.2)
/IO11: J1.24, R12.1, RN3.8 (R1.2)
/IO12: J1.25, R13.1, RN4.5 (R4.2)
/IO13: J1.28, R14.1, RN4.6 (R3.2)
/IO14: J1.29, R15.1, RN4.7 (R2.2)
/IO15: J1.32, R16.1, RN4.8 (R1.2)
GND: C1.2, C2.2, C3.2, C4.2, C5.2, C6.2, C7.2, C8.2, C9.2, C10.2, C11.2, C12.2, C13.2, C14.2, C15.2, C16.2, J1.2, J1.3, J1.6, J1.7, J1.10, J1.11, J1.14, J1.15, J1.18, J1.19, J1.22, J1.23, J1.26, J1.27, J1.30, J1.31
unnamed: C1.1, R1.2
unnamed: C2.1, R2.2
unnamed: C3.1, R3.2
unnamed: C4.1, R4.2
unnamed: C5.1, R5.2
unnamed: C6.1, R6.2
unnamed: C7.1, R7.2
unnamed: C8.1, R8.2
unnamed: C9.1, R9.2
unnamed: C10.1, R10.2
unnamed: C11.1, R11.2
unnamed: C12.1, R12.2
unnamed: C13.1, R13.2
unnamed: C14.1, R14.2
unnamed: C15.1, R15.2
unnamed: C16.1, R16.2

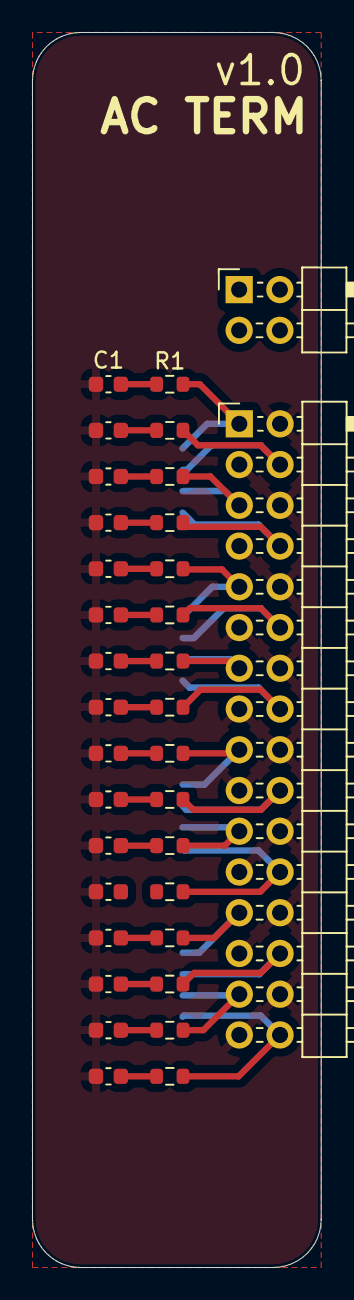
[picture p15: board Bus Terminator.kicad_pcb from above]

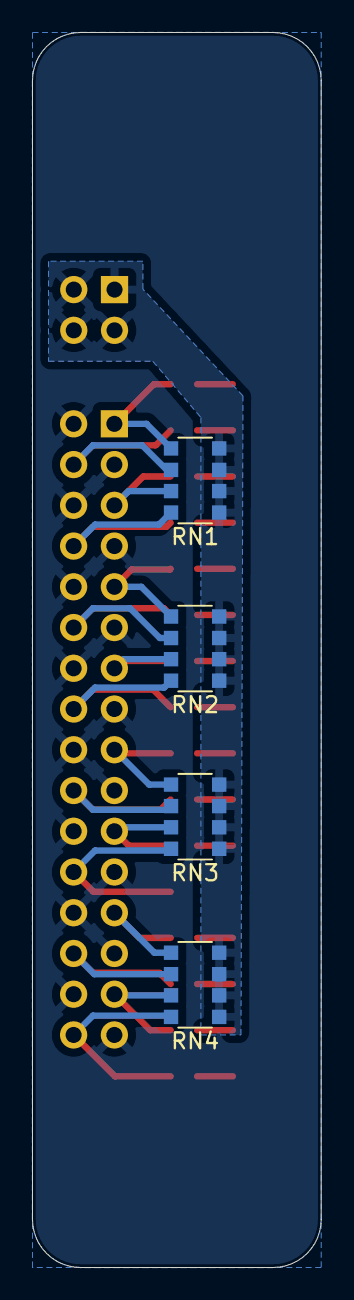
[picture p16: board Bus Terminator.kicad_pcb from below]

Board: 2 copper layers, 18.0 x 77.0 mm, 38 parts (4 on the bottom side), 34 nets.

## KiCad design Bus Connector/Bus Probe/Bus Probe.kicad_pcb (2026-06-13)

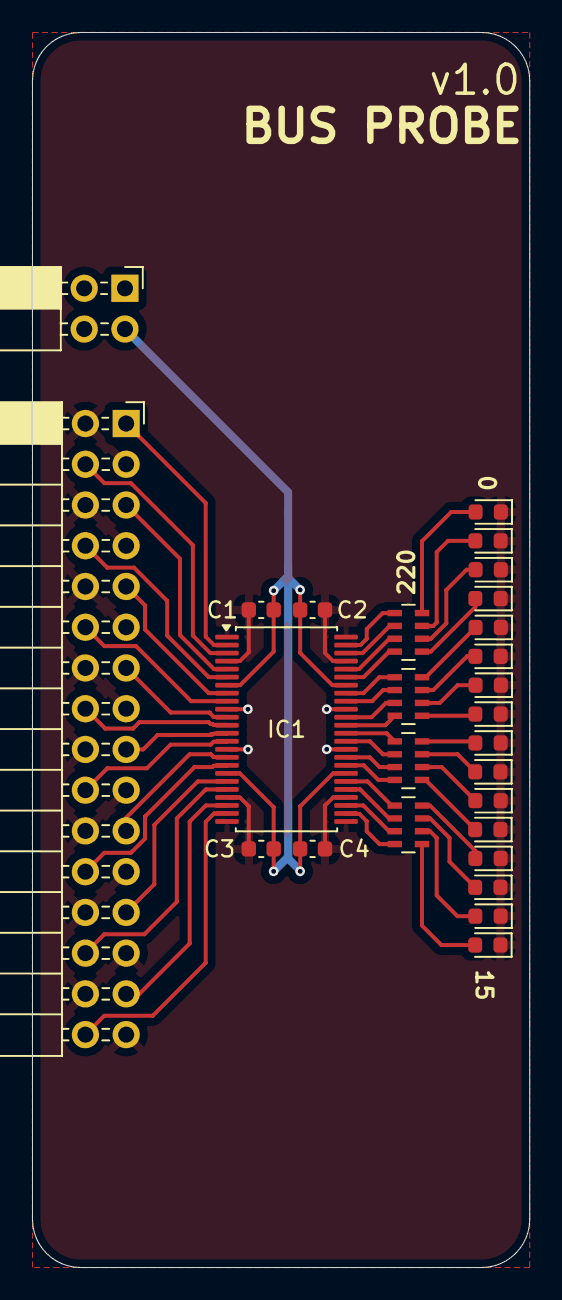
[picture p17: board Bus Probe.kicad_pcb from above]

Board: 2 copper layers, 31.0 x 77.0 mm, 27 parts (0 on the bottom side), 50 nets.

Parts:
C1, C2, C3, C4: 0.01uF; C_0603_1608Metric
D1, D2, D3, D4, D5, D6, D7, D8, D9, D10, D11, D12, D13, D14, D15, D16: LED_Small; LED_0603_1608Metric
IC1: SN74AHCT16245DGGR; TSSOP-48_6.1x12.5mm_P0.5mm
J1: Conn_02x16_Odd_Even; PinSocket_2x16_P2.54mm_Horizontal
J2: Conn_02x02_Counter_Clockwise; PinSocket_2x02_P2.54mm_Horizontal
RN1, RN2, RN3, RN4: R_Pack04; R_Array_Concave_4x0603

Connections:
+5V: C1.1, C2.1, C3.1, C4.1, IC1.7 (VCC), IC1.18 (VCC), IC1.31 (VCC), IC1.42 (VCC), J2.1, J2.2, J2.3, J2.4
/B0: IC1.47 (A0), RN1.1 (R1.1)
/B1: IC1.46 (A1), RN1.2 (R2.1)
/B2: IC1.44 (A2), RN1.3 (R3.1)
/B3: IC1.43 (A3), RN1.4 (R4.1)
/B4: IC1.41 (A4), RN2.1 (R1.1)
/B5: IC1.40 (A5), RN2.2 (R2.1)
/B6: IC1.38 (A6), RN2.3 (R3.1)
/B7: IC1.37 (A7), RN2.4 (R4.1)
/B8: IC1.36 (A8), RN3.1 (R1.1)
/B9: IC1.35 (A9), RN3.2 (R2.1)
/B10: IC1.33 (A10), RN3.3 (R3.1)
/B11: IC1.32 (A11), RN3.4 (R4.1)
/B12: IC1.30 (A12), RN4.1 (R1.1)
/B13: IC1.29 (A13), RN4.2 (R2.1)
/B14: IC1.27 (A14), RN4.3 (R3.1)
/B15: IC1.26 (A15), RN4.4 (R4.1)
/IO0: IC1.2 (B0), J1.1
/IO1: IC1.3 (B1), J1.4
/IO2: IC1.5 (B2), J1.5
/IO3: IC1.6 (B3), J1.8
/IO4: IC1.8 (B4), J1.9
/IO5: IC1.9 (B5), J1.12
/IO6: IC1.11 (B6), J1.13
/IO7: IC1.12 (B7), J1.16
/IO8: IC1.13 (B8), J1.17
/IO9: IC1.14 (B9), J1.20
/IO10: IC1.16 (B10), J1.21
/IO11: IC1.17 (B11), J1.24
/IO12: IC1.19 (B12), J1.25
/IO13: IC1.20 (B13), J1.28
/IO14: IC1.22 (B14), J1.29
/IO15: IC1.23 (B15), J1.32
GND: C1.2, C2.2, C3.2, C4.2, D1.1 (K), D2.1 (K), D3.1 (K), D4.1 (K), D5.1 (K), D6.1 (K), D7.1 (K), D8.1 (K), D9.1 (K), D10.1 (K), D11.1 (K), D12.1 (K), D13.1 (K), D14.1 (K), D15.1 (K), D16.1 (K), IC1.1 (T/~R1), IC1.4 (GND), IC1.10 (GND), IC1.15 (GND), IC1.21 (GND), IC1.24 (T/~R2), IC1.25 (~OE2), IC1.28 (GND), IC1.34 (GND), IC1.39 (GND), IC1.45 (GND), IC1.48 (~OE1), J1.2, J1.3, J1.6, J1.7, J1.10, J1.11, J1.14, J1.15, J1.18, J1.19, J1.22, J1.23, J1.26, J1.27, J1.30, J1.31
unnamed: D1.2 (A), RN1.8 (R1.2)
unnamed: D2.2 (A), RN1.6 (R3.2)
unnamed: D3.2 (A), RN2.8 (R1.2)
unnamed: D4.2 (A), RN2.6 (R3.2)
unnamed: D5.2 (A), RN3.8 (R1.2)
unnamed: D6.2 (A), RN3.6 (R3.2)
unnamed: D7.2 (A), RN4.8 (R1.2)
unnamed: D8.2 (A), RN4.6 (R3.2)
unnamed: D9.2 (A), RN1.7 (R2.2)
unnamed: D10.2 (A), RN1.5 (R4.2)
unnamed: D11.2 (A), RN2.7 (R2.2)
unnamed: D12.2 (A), RN2.5 (R4.2)
unnamed: D13.2 (A), RN3.7 (R2.2)
unnamed: D14.2 (A), RN3.5 (R4.2)
unnamed: D15.2 (A), RN4.7 (R2.2)
unnamed: D16.2 (A), RN4.5 (R4.2)

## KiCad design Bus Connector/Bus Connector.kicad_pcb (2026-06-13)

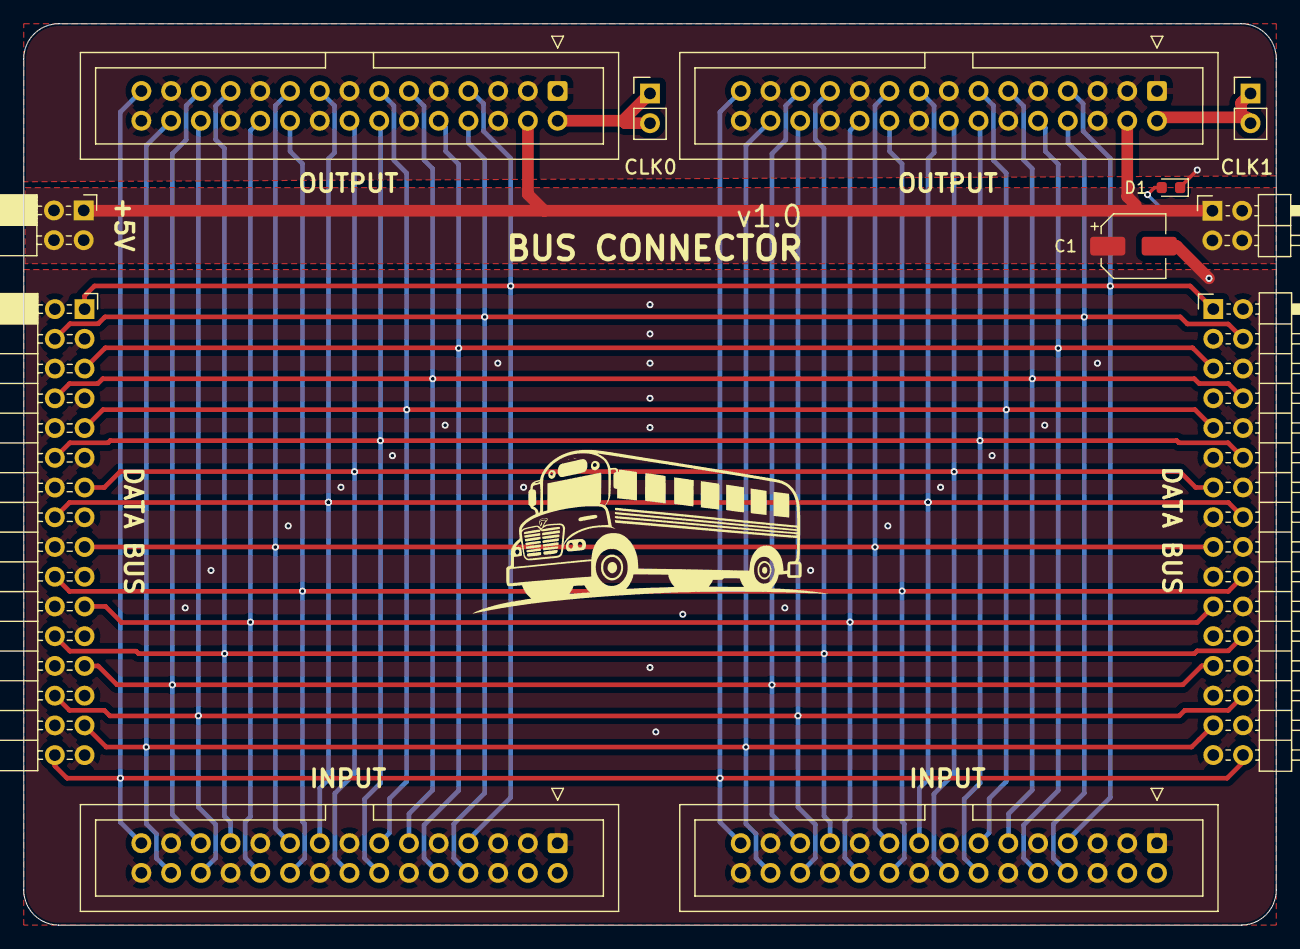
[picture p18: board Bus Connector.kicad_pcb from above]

Board: 2 copper layers, 107.0 x 77.0 mm, 13 parts (1 on the bottom side), 21 nets.

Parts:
C1: 100uF; CP_Elec_5x5.3
D1: LED; LED_0603_1608Metric
J1: Conn_02x16_Odd_Even; PinSocket_2x16_P2.54mm_Horizontal
J2: Conn_02x16_Odd_Even; PinHeader_2x16_P2.54mm_Horizontal
J3: Conn_02x02_Counter_Clockwise; PinHeader_2x02_P2.54mm_Horizontal
J4: Conn_02x02_Counter_Clockwise; PinSocket_2x02_P2.54mm_Horizontal
J5, J6, J7, J8: Conn_02x15_Odd_Even; IDC-Header_2x15_P2.54mm_Vertical
J9, J10: Conn_01x02_Pin; PinHeader_1x02_P2.54mm_Vertical
R1: 220; R_0603_1608Metric

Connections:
+5V: C1.1, J3.1, J3.2, J3.3, J3.4, J4.1, J4.2, J4.3, J4.4, J7.4, J8.4, R1.1
/IO0: J1.1, J2.1, J5.7, J6.7, J7.7, J8.7
/IO1: J1.4, J2.4, J5.8, J6.8, J7.8, J8.8
/IO2: J1.5, J2.5, J5.10, J6.10, J7.10, J8.10
/IO3: J1.8, J2.8, J5.11, J6.11, J7.11, J8.11
/IO4: J1.9, J2.9, J5.13, J6.13, J7.13, J8.13
/IO5: J1.12, J2.12, J5.14, J6.14, J7.14, J8.14
/IO6: J1.13, J2.13, J5.16, J6.16, J7.16, J8.16
/IO7: J1.16, J2.16, J5.17, J6.17, J7.17, J8.17
/IO8: J1.17, J2.17, J5.19, J6.19, J7.19, J8.19
/IO9: J1.20, J2.20, J5.20, J6.20, J7.20, J8.20
/IO10: J1.21, J2.21, J5.22, J6.22, J7.22, J8.22
/IO11: J1.24, J2.24, J5.23, J6.23, J7.23, J8.23
/IO12: J1.25, J2.25, J5.25, J6.25, J7.25, J8.25
/IO13: J1.28, J2.28, J5.26, J6.26, J7.26, J8.26
/IO14: J1.29, J2.29, J5.28, J6.28, J7.28, J8.28
/IO15: J1.32, J2.32, J5.29, J6.29, J7.29, J8.29
/bus_conn2/CLK: J7.2, J10.1, J10.2
/bus_conn3/CLK: J8.2, J9.1, J9.2
GND: C1.2, D1.1 (K), J1.2, J1.3, J1.6, J1.7, J1.10, J1.11, J1.14, J1.15, J1.18, J1.19, J1.22, J1.23, J1.26, J1.27, J1.30, J1.31, J2.2, J2.3, J2.6, J2.7, J2.10, J2.11, J2.14, J2.15, J2.18, J2.19, J2.22, J2.23, J2.26, J2.27, J2.30, J2.31, J5.1, J5.3, J5.5, J5.6, J5.9, J5.12, J5.15, J5.18, J5.21, J5.24, J5.27, J5.30, J6.1, J6.3, J6.5, J6.6, J6.9, J6.12, J6.15, J6.18, J6.21, J6.24, J6.27, J6.30, J7.1, J7.3, J7.5, J7.6, J7.9, J7.12, J7.15, J7.18, J7.21, J7.24, J7.27, J7.30, J8.1, J8.3, J8.5, J8.6, J8.9, J8.12, J8.15, J8.18, J8.21, J8.24, J8.27, J8.30
unnamed: D1.2 (A), R1.2

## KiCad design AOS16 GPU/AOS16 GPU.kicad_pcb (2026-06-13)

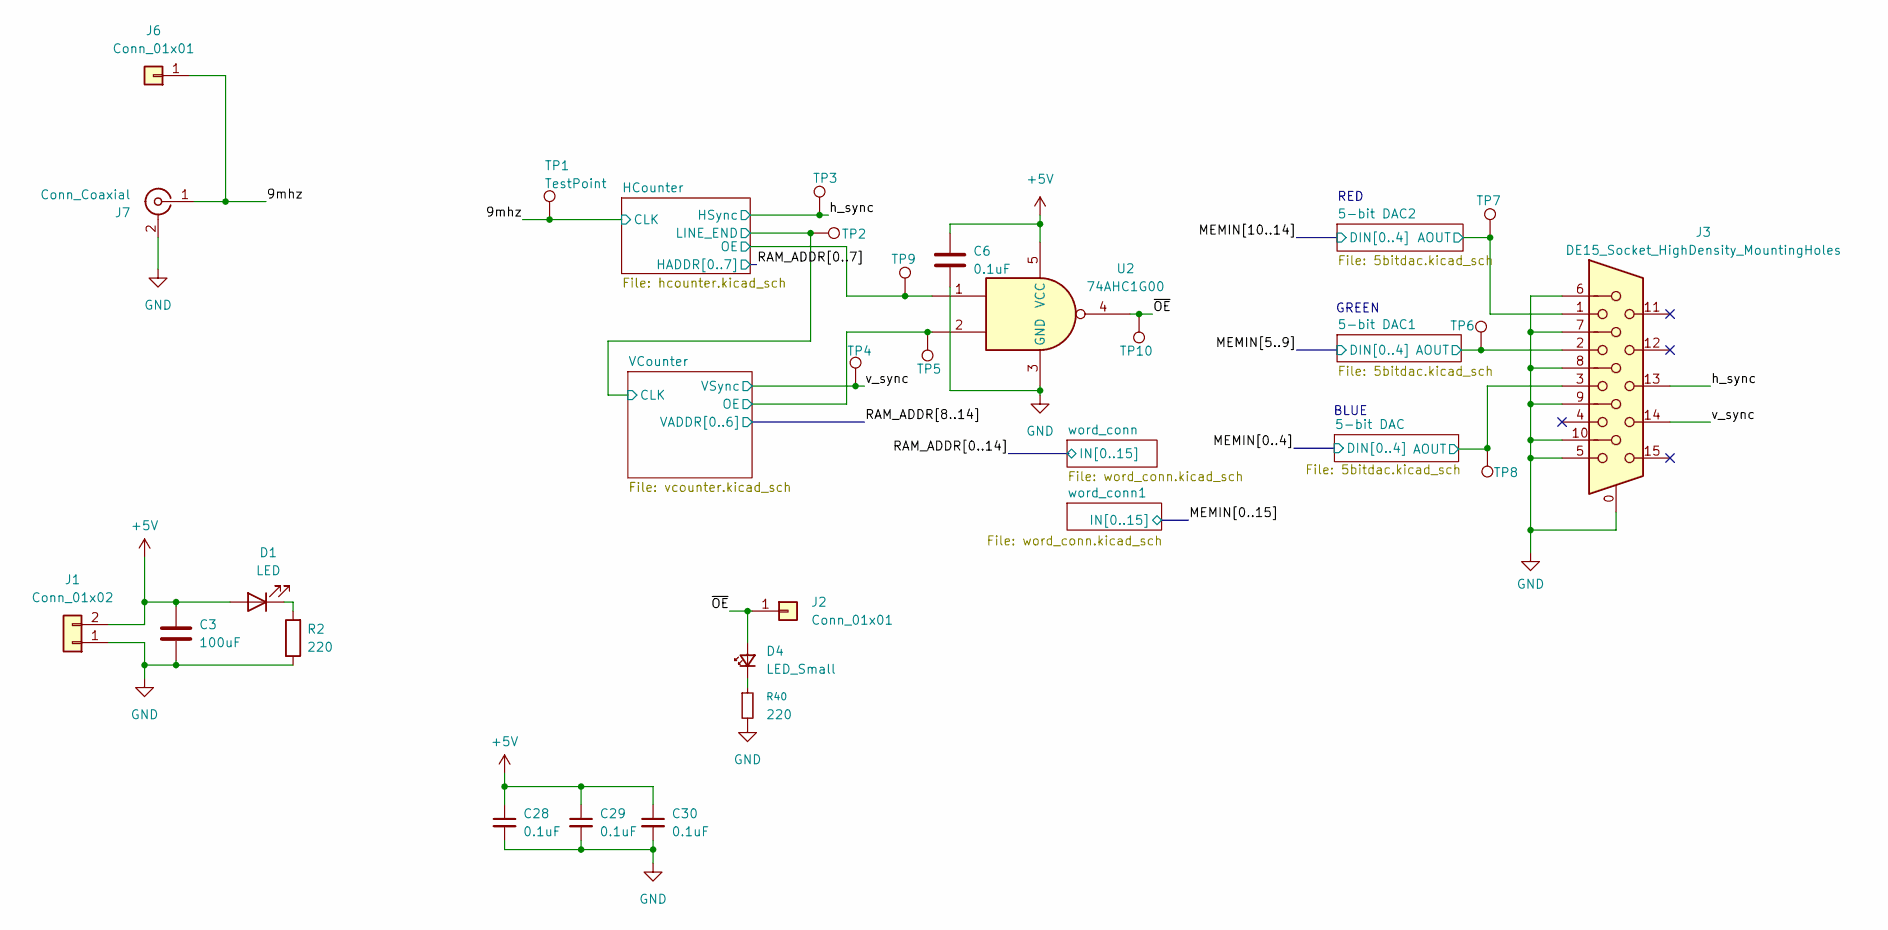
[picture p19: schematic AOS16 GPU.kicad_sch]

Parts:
C3: 100uF; CP_Elec_5x5.3
C6, C28, C29, C30: 0.1uF; C_0603_1608Metric
D1: LED; LED_0603_1608Metric
D4: LED_Small; LED_0603_1608Metric
J1: Conn_01x02; PinHeader_1x02_P2.54mm_Vertical
J2, J6: Conn_01x01; PinHeader_1x01_P2.54mm_Vertical
J3: DE15_Socket_HighDensity_MountingHoles; DSUB-15-HD_Socket_Horizontal_P2.29x1.90mm_EdgePinOffset3.03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
J7: Conn_Coaxial; SMA_Amphenol_132289_EdgeMount
R2, R40: 220; R_0603_1608Metric
TP1, TP2, TP3, TP4, TP5, TP6, TP7, TP8, TP9, TP10: TestPoint; TestPoint_Pad_D2.0mm
U2: 74AHC1G00; SOT-23-5

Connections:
+5V: C3.1, C6.1, C28.1, C29.1, C30.1, D1.2 (A), J1.2, U2.5 (VCC); also elsewhere on the board
/5-bit DAC1/AOUT: J3.2, TP6.1; also elsewhere on the board
/5-bit DAC2/AOUT: J3.1, TP7.1; also elsewhere on the board
/5-bit DAC/AOUT: J3.3, TP8.1; also elsewhere on the board
/9mhz: J6.1, J7.1 (In), TP1.1; also elsewhere on the board
/HCounter/OE: TP9.1, U2.1; also elsewhere on the board
/HCounter/~READ SET: TP2.1; also elsewhere on the board
/VCounter/OE: TP5.1, U2.2; also elsewhere on the board
/h_sync: J3.13, TP3.1; also elsewhere on the board
/v_sync: J3.14, TP4.1; also elsewhere on the board
/~OE: D4.2 (A), J2.1, TP10.1, U2.4
GND: C3.2, C6.2, C28.2, C29.2, C30.2, J1.1, J3.0, J3.5, J3.6, J3.7, J3.8, J3.9, J3.10, J7.2 (Ext), R2.1, R40.2, U2.3 (GND); also elsewhere on the board
unnamed: D1.1 (K), R2.2
unnamed: D4.1 (K), R40.1

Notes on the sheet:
RED
BLUE
GREEN

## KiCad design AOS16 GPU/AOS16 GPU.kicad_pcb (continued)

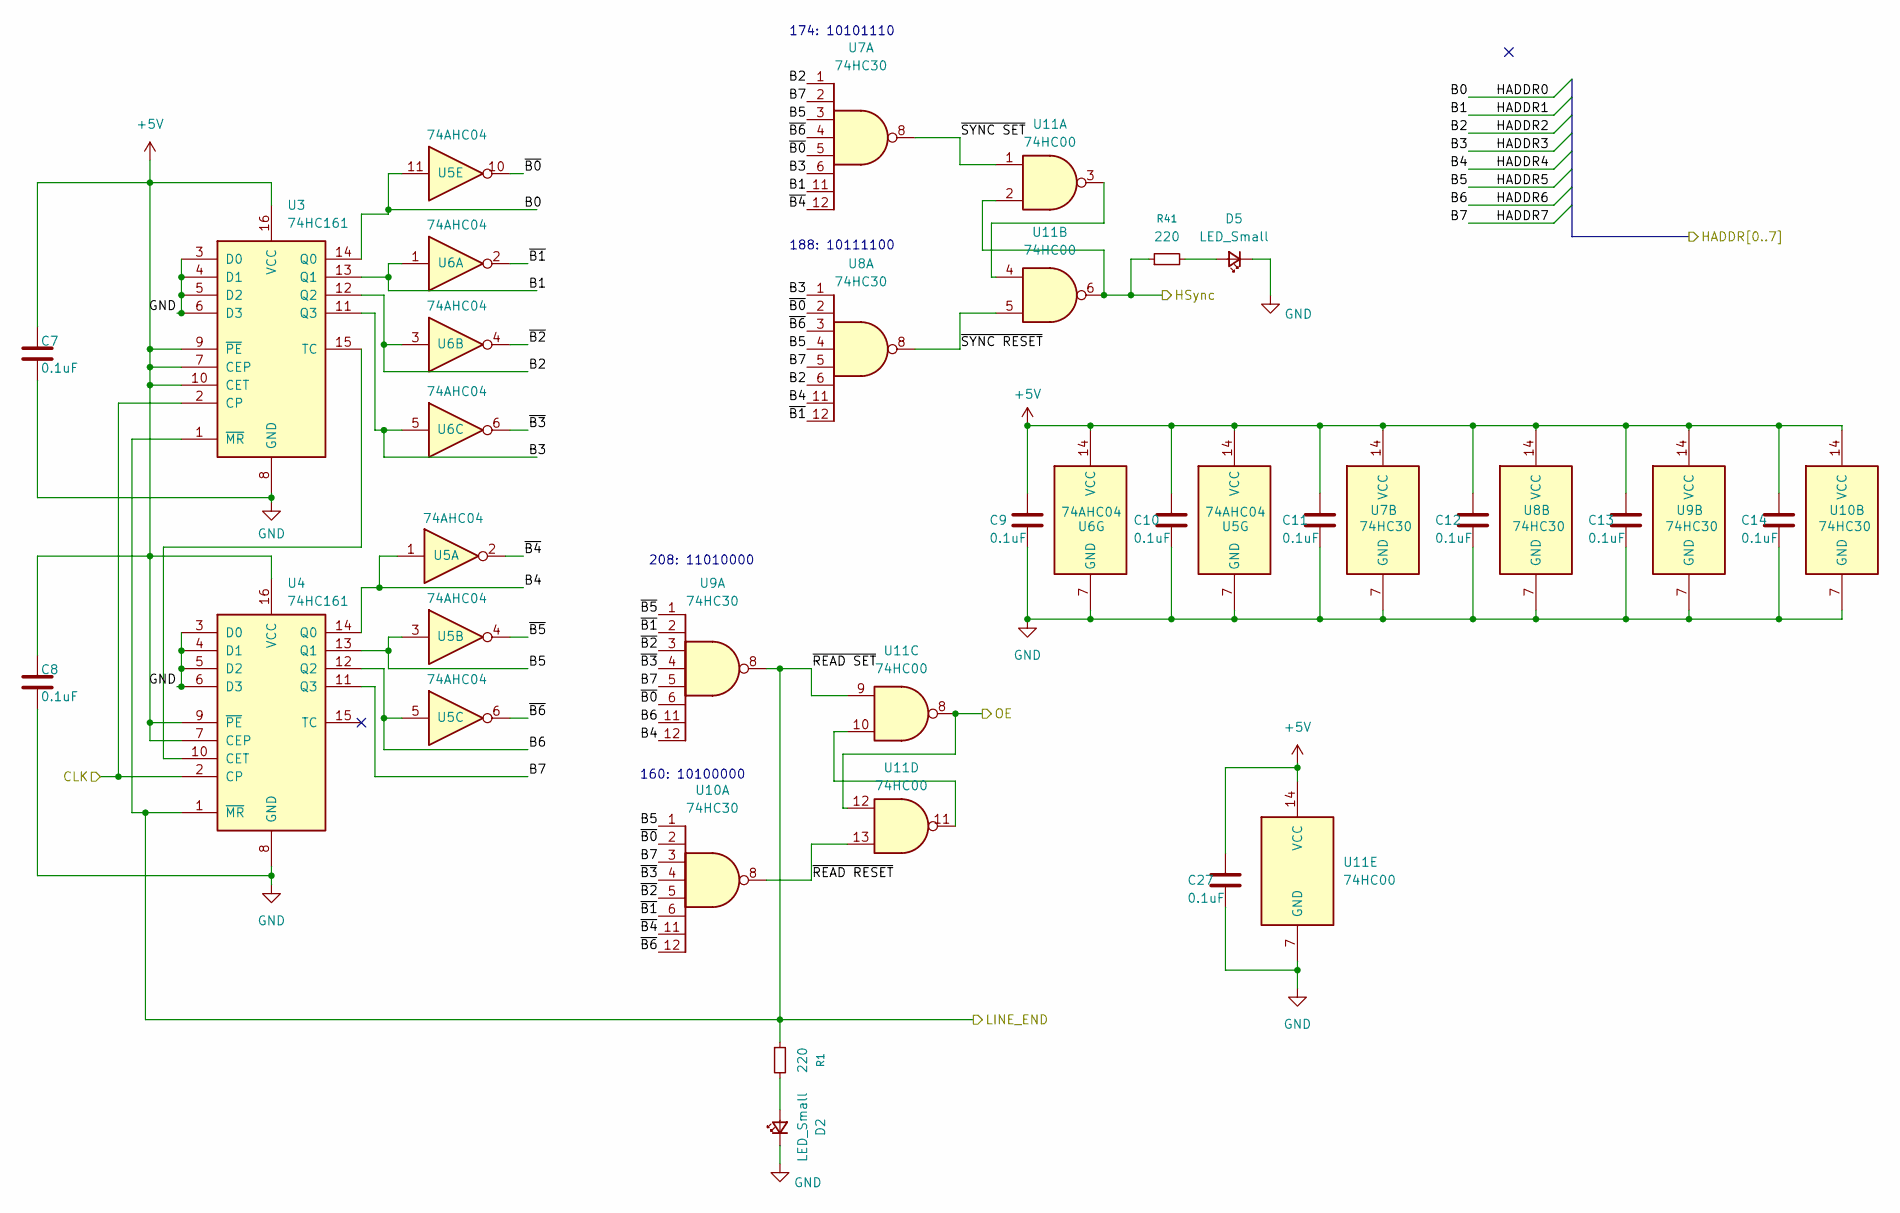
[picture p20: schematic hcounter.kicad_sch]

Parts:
C7, C8, C9, C10, C11, C12, C13, C14, C27: 0.1uF; C_0603_1608Metric
D2, D5: LED_Small; LED_0603_1608Metric
R1, R41: 220; R_0603_1608Metric
U3, U4: 74HC161; SOIC-16_3.9x9.9mm_P1.27mm
U5, U6: 74AHC04; SOIC-14_3.9x8.7mm_P1.27mm
U7, U8, U9, U10: 74HC30; SOIC-14_3.9x8.7mm_P1.27mm
U11: 74HC00; SOIC-14_3.9x8.7mm_P1.27mm

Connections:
+5V: C7.1, C8.1, C9.1, C10.1, C11.1, C12.1, C13.1, C14.1, C27.1, U3.7 (CEP), U3.9 (~PE), U3.10 (CET), U3.16 (VCC), U4.7 (CEP), U4.9 (~PE), U4.16 (VCC), U5.14 (VCC), U6.14 (VCC), U7.14 (VCC), U8.14 (VCC), U9.14 (VCC), U10.14 (VCC), U11.14 (VCC); also elsewhere on the board
/9mhz: U3.2 (CP), U4.2 (CP); also elsewhere on the board
/HCounter/OE: U11.8, U11.12; also elsewhere on the board
/HCounter/~B0: U5.10, U7.5, U8.2, U9.6, U10.2
/HCounter/~B1: U6.2, U8.12, U9.2, U10.6
/HCounter/~B2: U6.4, U9.3, U10.5
/HCounter/~B3: U6.6, U9.4, U10.4
/HCounter/~B4: U5.2, U7.12, U10.11
/HCounter/~B5: U5.4, U9.1
/HCounter/~B6: U5.6, U7.4, U8.3, U10.12
/HCounter/~READ RESET: U10.8, U11.13
/HCounter/~READ SET: R1.1, U3.1 (~MR), U4.1 (~MR), U9.8, U11.9; also elsewhere on the board
/HCounter/~SYNC RESET: U8.8, U11.5
/HCounter/~SYNC SET: U7.8, U11.1
/RAM_ADDR0: U3.14 (Q0), U5.11; also elsewhere on the board
/RAM_ADDR1: U3.13 (Q1), U6.1, U7.11; also elsewhere on the board
/RAM_ADDR2: U3.12 (Q2), U6.3, U7.1, U8.6; also elsewhere on the board
/RAM_ADDR3: U3.11 (Q3), U6.5, U7.6, U8.1; also elsewhere on the board
/RAM_ADDR4: U4.14 (Q0), U5.1, U8.11, U9.12; also elsewhere on the board
/RAM_ADDR5: U4.13 (Q1), U5.3, U7.3, U8.4, U10.1; also elsewhere on the board
/RAM_ADDR6: U4.12 (Q2), U5.5, U9.11; also elsewhere on the board
/RAM_ADDR7: U4.11 (Q3), U7.2, U8.5, U9.5, U10.3; also elsewhere on the board
/h_sync: R41.1, U11.2, U11.6; also elsewhere on the board
GND: C7.2, C8.2, C9.2, C10.2, C11.2, C12.2, C13.2, C14.2, C27.2, D2.1 (K), D5.1 (K), U3.3 (D0), U3.4 (D1), U3.5 (D2), U3.6 (D3), U3.8 (GND), U4.3 (D0), U4.4 (D1), U4.5 (D2), U4.6 (D3), U4.8 (GND), U5.7 (GND), U6.7 (GND), U7.7 (GND), U8.7 (GND), U9.7 (GND), U10.7 (GND), U11.7 (GND); also elsewhere on the board
unnamed: D2.2 (A), R1.2
unnamed: D5.2 (A), R41.2
unnamed: U3.15 (TC), U4.10 (CET)
unnamed: U11.3, U11.4
unnamed: U11.10, U11.11

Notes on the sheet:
160: 10100000
188: 10111100
174: 10101110
208: 11010000


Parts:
C1: 100 pF; C_0603_1608Metric
C23: 0.1uF; C_0603_1608Metric
R4, R5, R7, R9, R11, R13: 2k; R_0603_1608Metric
R6, R8, R10, R12: 1k; R_0603_1608Metric
R14: 402; R_0402_1005Metric
R37: 75; R_0603_1608Metric
U22: LMH6642; SOT-23-5

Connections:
+5V: C1.1, C23.1, U22.5 (V+); also elsewhere on the board
/5-bit DAC1/AOUT: R37.2; also elsewhere on the board
/MEMIN5: R5.2; also elsewhere on the board
/MEMIN6: R7.2; also elsewhere on the board
/MEMIN7: R9.2; also elsewhere on the board
/MEMIN8: R11.2; also elsewhere on the board
/MEMIN9: R13.2; also elsewhere on the board
GND: C1.2, C23.2, R4.1, R14.2, U22.2 (V-); also elsewhere on the board
unnamed: R4.2, R5.1, R6.1
unnamed: R6.2, R7.1, R8.1
unnamed: R8.2, R9.1, R10.1
unnamed: R10.2, R11.1, R12.1
unnamed: R12.2, R13.1, R14.1, U22.3 (+)
unnamed: R37.1, U22.1, U22.4 (-)

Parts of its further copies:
C2, C4: 100 pF; C_0603_1608Metric
C24, C25: 0.1uF; C_0603_1608Metric
R15, R16, R18, R20, R22, R24, R26, R27, R29, R31, R33, R35: 2k; R_0603_1608Metric
R17, R19, R21, R23, R28, R30, R32, R34: 1k; R_0603_1608Metric
R25, R36: 402; R_0402_1005Metric
R38, R39: 75; R_0603_1608Metric
U23, U24: LMH6642; SOT-23-5

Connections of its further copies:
+5V: C2.1, C4.1, C24.1, C25.1, U23.5 (V+), U24.5 (V+); also elsewhere on the board
/5-bit DAC2/AOUT: R39.2; also elsewhere on the board
/5-bit DAC/AOUT: R38.2; also elsewhere on the board
/MEMIN0: R16.2; also elsewhere on the board
/MEMIN1: R18.2; also elsewhere on the board
/MEMIN2: R20.2; also elsewhere on the board
/MEMIN3: R22.2; also elsewhere on the board
/MEMIN4: R24.2; also elsewhere on the board
/MEMIN10: R27.2; also elsewhere on the board
/MEMIN11: R29.2; also elsewhere on the board
/MEMIN12: R31.2; also elsewhere on the board
/MEMIN13: R33.2; also elsewhere on the board
/MEMIN14: R35.2; also elsewhere on the board
GND: C2.2, C4.2, C24.2, C25.2, R15.1, R25.2, R26.1, R36.2, U23.2 (V-), U24.2 (V-); also elsewhere on the board
unnamed: R15.2, R16.1, R17.1
unnamed: R17.2, R18.1, R19.1
unnamed: R19.2, R20.1, R21.1
unnamed: R21.2, R22.1, R23.1
unnamed: R26.2, R27.1, R28.1
unnamed: R28.2, R29.1, R30.1
unnamed: R30.2, R31.1, R32.1
unnamed: R32.2, R33.1, R34.1
unnamed: R23.2, R24.1, R25.1, U23.3 (+)
unnamed: R38.1, U23.1, U23.4 (-)
unnamed: R34.2, R35.1, R36.1, U24.3 (+)
unnamed: R39.1, U24.1, U24.4 (-)


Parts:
J4: Conn_02x08_Top_Bottom; PinHeader_2x08_P2.54mm_Vertical

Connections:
/RAM_ADDR0: J4.1; also elsewhere on the board
/RAM_ADDR1: J4.2; also elsewhere on the board
/RAM_ADDR2: J4.3; also elsewhere on the board
/RAM_ADDR3: J4.4; also elsewhere on the board
/RAM_ADDR4: J4.5; also elsewhere on the board
/RAM_ADDR5: J4.6; also elsewhere on the board
/RAM_ADDR6: J4.7; also elsewhere on the board
/RAM_ADDR7: J4.8; also elsewhere on the board
/RAM_ADDR8: J4.9; also elsewhere on the board
/RAM_ADDR9: J4.10; also elsewhere on the board
/RAM_ADDR10: J4.11; also elsewhere on the board
/RAM_ADDR11: J4.12; also elsewhere on the board
/RAM_ADDR12: J4.13; also elsewhere on the board
/RAM_ADDR13: J4.14; also elsewhere on the board
/RAM_ADDR14: J4.15; also elsewhere on the board
/word_conn/IN15: J4.16

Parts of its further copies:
J5: Conn_02x08_Top_Bottom; PinHeader_2x08_P2.54mm_Vertical

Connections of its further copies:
/MEMIN0: J5.1; also elsewhere on the board
/MEMIN1: J5.2; also elsewhere on the board
/MEMIN2: J5.3; also elsewhere on the board
/MEMIN3: J5.4; also elsewhere on the board
/MEMIN4: J5.5; also elsewhere on the board
/MEMIN5: J5.6; also elsewhere on the board
/MEMIN6: J5.7; also elsewhere on the board
/MEMIN7: J5.8; also elsewhere on the board
/MEMIN8: J5.9; also elsewhere on the board
/MEMIN9: J5.10; also elsewhere on the board
/MEMIN10: J5.11; also elsewhere on the board
/MEMIN11: J5.12; also elsewhere on the board
/MEMIN12: J5.13; also elsewhere on the board
/MEMIN13: J5.14; also elsewhere on the board
/MEMIN14: J5.15; also elsewhere on the board
/MEMIN15: J5.16


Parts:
C15, C16, C17, C18, C19, C20, C21, C22, C26: 0.1uF; C_0603_1608Metric
D3, D6: LED_Small; LED_0603_1608Metric
R3, R42: 220; R_0603_1608Metric
TP11: NEW FRAME; TestPoint_Pad_D2.0mm
U12: 74AHC04; SOIC-14_3.9x8.7mm_P1.27mm
U13, U14, U15, U16: 74HC30; SOIC-14_3.9x8.7mm_P1.27mm
U17, U18, U19: 74HC161; SOIC-16_3.9x9.9mm_P1.27mm
U20: 74HC21; SOIC-14_3.9x8.7mm_P1.27mm
U21: 74HC00; SOIC-14_3.9x8.7mm_P1.27mm

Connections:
+5V: C15.1, C16.1, C17.1, C18.1, C19.1, C20.1, C21.1, C22.1, C26.1, U12.14 (VCC), U13.11, U13.12, U13.14 (VCC), U14.11, U14.12, U14.14 (VCC), U15.11, U15.12, U15.14 (VCC), U16.11, U16.12, U16.14 (VCC), U17.7 (CEP), U17.9 (~PE), U17.10 (CET), U17.16 (VCC), U18.7 (CEP), U18.9 (~PE), U18.16 (VCC), U19.7 (CEP), U19.9 (~PE), U19.16 (VCC), U20.14 (VCC); also elsewhere on the board
/HCounter/~READ SET: U17.2 (CP), U18.2 (CP), U19.2 (CP); also elsewhere on the board
/RAM_ADDR8: U12.5, U14.1, U15.5, U17.12 (Q2); also elsewhere on the board
/RAM_ADDR9: U12.9, U15.3, U17.11 (Q3); also elsewhere on the board
/RAM_ADDR10: U12.11, U15.2, U18.14 (Q0); also elsewhere on the board
/RAM_ADDR11: U18.13 (Q1), U20.2; also elsewhere on the board
/RAM_ADDR12: U18.12 (Q2), U20.4; also elsewhere on the board
/RAM_ADDR13: U18.11 (Q3), U20.5; also elsewhere on the board
/RAM_ADDR14: U19.14 (Q0), U20.1; also elsewhere on the board
/VCounter/B0: U12.1, U13.6, U15.1, U17.14 (Q0)
/VCounter/B1: U12.3, U17.13 (Q1)
/VCounter/OE: U21.8, U21.12; also elsewhere on the board
/VCounter/~B0: U12.2, U14.2, U16.1
/VCounter/~B1: U12.4, U13.5, U14.3, U15.6, U16.2
/VCounter/~B2: U12.6, U13.3, U16.4
/VCounter/~B3: U12.8, U13.4, U14.4, U16.3
/VCounter/~B4: U12.10, U13.1, U14.6, U16.5
/VCounter/~READ RESET: U16.8, U21.13
/VCounter/~READ SET: R3.1, TP11.1, U15.8, U17.1 (~MR), U18.1 (~MR), U19.1 (~MR), U21.9
/VCounter/~SYNC RESET: U14.8, U21.5
/VCounter/~SYNC SET: U13.8, U21.1
/v_sync: R42.1, U21.2, U21.6; also elsewhere on the board
GND: C15.2, C16.2, C17.2, C18.2, C19.2, C20.2, C21.2, C22.2, C26.2, D3.1 (K), D6.1 (K), U12.7 (GND), U13.7 (GND), U14.7 (GND), U15.7 (GND), U16.7 (GND), U17.3 (D0), U17.4 (D1), U17.5 (D2), U17.6 (D3), U17.8 (GND), U18.3 (D0), U18.4 (D1), U18.5 (D2), U18.6 (D3), U18.8 (GND), U19.3 (D0), U19.4 (D1), U19.5 (D2), U19.6 (D3), U19.8 (GND), U20.7 (GND); also elsewhere on the board
unnamed: D3.2 (A), R3.2
unnamed: D6.2 (A), R42.2
unnamed: U13.2, U14.5, U15.4, U16.6, U20.6
unnamed: U17.15 (TC), U18.10 (CET)
unnamed: U18.15 (TC), U19.10 (CET)
unnamed: U21.3, U21.4
unnamed: U21.10, U21.11

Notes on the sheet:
480: 0001 1110 0000
484: 0001 1110 0100
509: 0001 1111 1101
481: 0001 1110 0001



Board: 4 copper layers, 81.0 x 60.0 mm, 118 parts (34 on the bottom side), 95 nets.

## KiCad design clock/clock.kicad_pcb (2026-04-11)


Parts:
C1, C2, C3, C4, C5, C11, C12: 0.1uF; C_0603_1608Metric
C6, C7: 0.01uF; C_0603_1608Metric
C8, C9: 33pF; C_0603_1608Metric
C10: 1uF; C_0603_1608Metric
C13: 100uF; CP_Elec_5x5.3
D1: LED; LED_0603_1608Metric
J1: Conn_02x03_Odd_Even; PinHeader_2x03_P2.54mm_Vertical
J2: Conn_01x08; PinHeader_1x08_P2.54mm_Vertical
J3: Conn_01x02; PinHeader_1x02_P2.54mm_Vertical
R1, R2, R4: 1M; R_0603_1608Metric
R3: 100; R_0603_1608Metric
R5, R6: 1k; R_0603_1608Metric
R7: 220; R_0603_1608Metric
RN1, RN2: 33; R_Array_Convex_4x1206
RV1: 1M; Potentiometer_Piher_PT-6-V_Vertical
SW1: SW_Push; SW_PUSH_6mm
U1, U4, U5: 74AHCT1G14; SOT-23-5
U2, U3: LM555xM; SOIC-8_3.9x4.9mm_P1.27mm
U6: 74AHC541; TSSOP-20_4.4x6.5mm_P0.65mm
Y1: 10MHz; Crystal_HC49-U_Vertical

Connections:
+5V: C1.1, C2.1, C3.1, C4.1, C5.1, C12.1, C13.1, J3.2, R1.1, R4.1, R5.1, U1.5 (VCC), U2.4 (R), U2.8 (VCC), U3.4 (R), U3.8 (VCC), U4.5 (VCC), U5.5 (VCC), U6.20 (VCC)
GND: C1.2, C2.2, C3.2, C4.2, C5.2, C6.2, C7.2, C8.2, C9.2, C10.2, C11.2, C12.2, C13.2, D1.1 (K), J3.1, SW1.1, U1.3 (GND), U2.1 (GND), U3.1 (GND), U4.3 (GND), U5.3 (GND), U6.1 (G1), U6.10 (GND), U6.19 (G2)
unnamed: C8.1, R2.1, U1.2, Y1.1
unnamed: C9.1, R3.2, Y1.2
unnamed: D1.2 (A), R7.2
unnamed: J1.1, R2.2, R3.1, U1.4
unnamed: J1.2, J1.4, J1.6, U6.2 (A0), U6.3 (A1), U6.4 (A2), U6.5 (A3), U6.6 (A4), U6.7 (A5), U6.8 (A6), U6.9 (A7)
unnamed: J1.3, U4.4
unnamed: J1.5, U5.4
unnamed: J2.1, RN1.4 (R4.1)
unnamed: J2.2, RN1.3 (R3.1)
unnamed: J2.3, RN1.2 (R2.1)
unnamed: J2.4, RN1.1 (R1.1)
unnamed: J2.5, RN2.4 (R4.1)
unnamed: J2.6, RN2.3 (R3.1)
unnamed: J2.7, RN2.2 (R2.1)
unnamed: J2.8, RN2.1 (R1.1)
unnamed: R6.2, RV1.2
unnamed: RN1.8 (R1.2), U6.15 (Y3)
unnamed: RN1.7 (R2.2), U6.16 (Y2)
unnamed: RN1.6 (R3.2), U6.17 (Y1)
unnamed: RN1.5 (R4.2), U6.18 (Y0)
unnamed: RN2.8 (R1.2), U6.14 (Y4)
unnamed: RN2.7 (R2.2), U6.13 (Y5)
unnamed: RN2.6 (R3.2), U6.12 (Y6)
unnamed: R7.1, RN2.5 (R4.2), U6.11 (Y7)
unnamed: C6.1, U2.5 (CV)
unnamed: C11.1, R4.2, U2.6 (THR), U2.7 (DIS)
unnamed: U2.3 (Q), U4.2
unnamed: R1.2, SW1.2, U2.2 (TR)
unnamed: C7.1, U3.5 (CV)
unnamed: R5.2, R6.1, U3.7 (DIS)
unnamed: U3.3 (Q), U5.2
unnamed: C10.1, RV1.3, U3.2 (TR), U3.6 (THR)


Board: 2 copper layers, 46.0 x 39.0 mm, 35 parts (0 on the bottom side), 34 nets.

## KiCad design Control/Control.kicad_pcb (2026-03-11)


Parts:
C1, C2, C4, C5, C6, C7: 0.1uF; C_0603_1608Metric
D1, D2, D3, D4, D5, D6, D7, D8, D9, D10, D11, D12, D13, D14, D15, D16, D17, D18, D19, D20, D21, D22, D23, D24, D25, D26, D27, D28, D29, D30, D31, D32: LED_Small; LED_0603_1608Metric
J1, J2: Conn_02x08_Odd_Even; PinHeader_2x08_P2.54mm_Vertical
J4: MCR-MCRI; PinHeader_1x02_P2.54mm_Vertical
J6, J9, J11: Conn_01x02; PinHeader_1x02_P2.54mm_Vertical
J12: Conn_01x01; PinHeader_1x01_P2.54mm_Vertical
R1, R2, R3, R4, R5, R6, R7, R8, R9, R10, R11, R12, R13, R14, R15, R16, R17, R18, R19, R20, R21, R22, R23, R24, R25, R26, R27, R28, R29, R30, R31, R32: 220; R_0603_1608Metric
TP5, TP6, TP7, TP8: TestPoint; TestPoint_Pad_D1.0mm
U1: 74AHC1G04; SOT-23-5
U3: 74LS161; SOIC-16_3.9x9.9mm_P1.27mm
U4, U5, U6, U7: SST39SF020; DIP-32_W15.24mm_Socket

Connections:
+5V: C1.1, C2.1, C4.1, C5.1, C6.1, C7.1, U1.5 (VCC), U3.7 (CEP), U3.9 (~PE), U3.10 (CET), U3.16 (VCC), U4.31 (PGM), U4.32 (VCC), U5.31 (PGM), U5.32 (VCC), U6.31 (PGM), U6.32 (VCC), U7.31 (PGM), U7.32 (VCC); also elsewhere on the board
/ALF0: J1.13, R13.1, U6.21 (D7)
/ALF1: J1.14, R14.1, U6.13 (D0)
/ALF2: J1.15, R15.1, U6.14 (D1)
/ALF3: J1.16, R16.1, U6.15 (D2)
/ALU interface/ALU_CARRY: J9.2; also elsewhere on the board
/CLK: U1.2; also elsewhere on the board
/CTR0: TP5.1, U3.14 (Q0), U4.12 (A0), U5.12 (A0), U6.12 (A0), U7.12 (A0)
/CTR1: TP7.1, U3.13 (Q1), U4.11 (A1), U5.11 (A1), U6.11 (A1), U7.11 (A1)
/CTR2: TP8.1, U3.12 (Q2), U4.10 (A2), U5.10 (A2), U6.10 (A2), U7.10 (A2)
/CTR3: TP6.1, U3.11 (Q3), U4.9 (A3), U5.9 (A3), U6.9 (A3), U7.9 (A3)
/D0: J2.9, R25.1, U5.17 (D3)
/D1: J2.10, R26.1, U5.18 (D4)
/D2: J2.11, R27.1, U5.19 (D5)
/D3: J2.12, R28.1, U5.20 (D6)
/D4: J2.13, R29.1, U5.21 (D7)
/D5: J2.14, R30.1, U5.13 (D0)
/D6: J2.15, R31.1, U5.14 (D1)
/D7: J2.16, R32.1, U5.15 (D2)
/HLT: J2.5, R21.1, U7.15 (D2)
/IRI: J1.5, R5.1
/JNZ: J2.8, R24.1, U7.14 (D1); also elsewhere on the board
/MSL: J1.3, R3.1, U4.15 (D2), U4.20 (D6)
/PCE: J2.2, J11.1, R18.1
/PCEi: U7.17 (D3); also elsewhere on the board
/RSEL0: J1.6, R6.1, U4.21 (D7)
/RSEL1: J1.7, R7.1, U4.13 (D0)
/RSEL2: J1.8, R8.1, U4.14 (D1)
/SWP: J2.7, R23.1, U7.13 (D0)
/jump logic/PCE: J11.2; also elsewhere on the board
/jump logic/~PCL: J6.2; also elsewhere on the board
/reg16/DOUT0: U4.3 (A15), U5.3 (A15), U6.3 (A15), U7.3 (A15); also elsewhere on the board
/reg16/DOUT1: U4.2 (A16), U5.2 (A16), U6.2 (A16), U7.2 (A16); also elsewhere on the board
/reg16/DOUT2: U4.4 (A12), U5.4 (A12), U6.4 (A12), U7.4 (A12); also elsewhere on the board
/reg16/DOUT3: U4.5 (A7), U5.5 (A7), U6.5 (A7), U7.5 (A7); also elsewhere on the board
/reg16/DOUT4: U4.6 (A6), U5.6 (A6), U6.6 (A6), U7.6 (A6); also elsewhere on the board
/reg16/DOUT5: U4.7 (A5), U5.7 (A5), U6.7 (A5), U7.7 (A5); also elsewhere on the board
/reg16/DOUT6: U4.8 (A4), U5.8 (A4), U6.8 (A4), U7.8 (A4); also elsewhere on the board
/reg16/DOUT7: U4.23 (A10), U5.23 (A10), U6.23 (A10), U7.23 (A10); also elsewhere on the board
/reg16/DOUT8: U4.25 (A11), U5.25 (A11), U6.25 (A11), U7.25 (A11); also elsewhere on the board
/reg16/DOUT9: U4.26 (A9), U5.26 (A9), U6.26 (A9), U7.26 (A9); also elsewhere on the board
/reg16/DOUT10: U4.27 (A8), U5.27 (A8), U6.27 (A8), U7.27 (A8); also elsewhere on the board
/reg16/DOUT11: U4.28 (A13), U5.28 (A13), U6.28 (A13), U7.28 (A13); also elsewhere on the board
/reg16/DOUT12: U4.29 (A14), U5.29 (A14), U6.29 (A14), U7.29 (A14); also elsewhere on the board
/reg16/DOUT13: U4.30 (A17), U5.30 (A17), U6.30 (A17), U7.30 (A17); also elsewhere on the board
/reg16/WE: J12.1; also elsewhere on the board
/register interface/FLG_GPU_READY: J9.1; also elsewhere on the board
/~ALO: J2.1, R17.1, U7.18 (D4); also elsewhere on the board
/~IN_{ALA}: J1.11, R11.1, U6.19 (D5)
/~IN_{ALB}: J1.12, R12.1, U6.20 (D6)
/~MAL: J1.4, R4.1, U4.19 (D5)
/~MCR: J2.6, J4.2, R22.1, U7.21 (D7)
/~MR: J1.2, R2.1, U4.17 (D3)
/~MW: J1.1, R1.1, U4.18 (D4)
/~PCL: J2.3, J6.1, R19.1
/~PCLi: U7.20 (D6); also elsewhere on the board
/~PCO: J2.4, R20.1, U7.19 (D5)
/~RGI: J1.9, R9.1, U6.17 (D3)
/~RGO: J1.10, R10.1, U6.18 (D4)
GND: C1.2, C2.2, C4.2, C5.2, C6.2, C7.2, D1.1 (K), D2.1 (K), D3.1 (K), D4.1 (K), D5.1 (K), D6.1 (K), D7.1 (K), D8.1 (K), D9.1 (K), D10.1 (K), D11.1 (K), D12.1 (K), D13.1 (K), D14.1 (K), D15.1 (K), D16.1 (K), D17.1 (K), D18.1 (K), D19.1 (K), D20.1 (K), D21.1 (K), D22.1 (K), D23.1 (K), D24.1 (K), D25.1 (K), D26.1 (K), D27.1 (K), D28.1 (K), D29.1 (K), D30.1 (K), D31.1 (K), D32.1 (K), U1.3 (GND), U3.8 (GND), U4.16 (GND), U4.22 (CE), U4.24 (OE), U5.16 (GND), U5.22 (CE), U5.24 (OE), U6.16 (GND), U6.22 (CE), U6.24 (OE), U7.16 (GND), U7.22 (CE), U7.24 (OE); also elsewhere on the board
unnamed: D1.2 (A), R1.2
unnamed: D2.2 (A), R2.2
unnamed: D3.2 (A), R3.2
unnamed: D4.2 (A), R4.2
unnamed: D5.2 (A), R5.2
unnamed: D6.2 (A), R6.2
unnamed: D7.2 (A), R7.2
unnamed: D8.2 (A), R8.2
unnamed: D9.2 (A), R9.2
unnamed: D10.2 (A), R10.2
unnamed: D11.2 (A), R11.2
unnamed: D12.2 (A), R12.2
unnamed: D13.2 (A), R13.2
unnamed: D14.2 (A), R14.2
unnamed: D15.2 (A), R15.2
unnamed: D16.2 (A), R16.2
unnamed: D17.2 (A), R17.2
unnamed: D18.2 (A), R18.2
unnamed: D19.2 (A), R19.2
unnamed: D20.2 (A), R20.2
unnamed: D21.2 (A), R21.2
unnamed: D22.2 (A), R22.2
unnamed: D23.2 (A), R23.2
unnamed: D24.2 (A), R24.2
unnamed: D25.2 (A), R25.2
unnamed: D26.2 (A), R26.2
unnamed: D27.2 (A), R27.2
unnamed: D28.2 (A), R28.2
unnamed: D29.2 (A), R29.2
unnamed: D30.2 (A), R30.2
unnamed: D31.2 (A), R31.2
unnamed: D32.2 (A), R32.2
unnamed: J4.1, U3.1 (~MR)
unnamed: U1.4, U3.2 (CP)

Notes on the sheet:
16..23
24..31
0..7
8..15


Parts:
C19, C20, C21, C22: 0.1uF; C_0603_1608Metric
J10: Conn_01x02; PinHeader_1x02_P2.54mm_Vertical
TP2, TP3, TP4: TestPoint; TestPoint_Pad_D1.0mm
U16, U17: 4078; SOIC-14_3.9x8.7mm_P1.27mm
U18: 74AHC1G32; SOT-23-5
U19: 74HC173; SOIC-16_3.9x9.9mm_P1.27mm

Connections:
+5V: C19.1, C20.1, C21.1, C22.1, U16.14 (Vdd), U17.14 (Vdd), U18.5 (VCC), U19.16 (VCC); also elsewhere on the board
/ALU interface/ALU_CARRY: U19.12 (D2); also elsewhere on the board
/ALU interface/ALU_ZERO: U18.4, U19.14 (D0)
/ALU interface/BUS0: U16.2; also elsewhere on the board
/ALU interface/BUS1: U16.3; also elsewhere on the board
/ALU interface/BUS2: U16.4; also elsewhere on the board
/ALU interface/BUS3: U16.5; also elsewhere on the board
/ALU interface/BUS4: U16.12; also elsewhere on the board
/ALU interface/BUS5: U16.11; also elsewhere on the board
/ALU interface/BUS6: U16.10; also elsewhere on the board
/ALU interface/BUS7: U16.9; also elsewhere on the board
/ALU interface/BUS8: U17.2; also elsewhere on the board
/ALU interface/BUS9: U17.3; also elsewhere on the board
/ALU interface/BUS10: U17.4; also elsewhere on the board
/ALU interface/BUS11: U17.5; also elsewhere on the board
/ALU interface/BUS12: U17.12; also elsewhere on the board
/ALU interface/BUS13: U17.11; also elsewhere on the board
/ALU interface/BUS14: U17.10; also elsewhere on the board
/ALU interface/BUS15: U17.9, U19.13 (D1); also elsewhere on the board
/ALU interface/FLG_CARRYo: TP4.1, U19.5 (Q2); also elsewhere on the board
/ALU interface/FLG_SIGNo: TP3.1, U19.4 (Q1); also elsewhere on the board
/ALU interface/FLG_ZEROo: TP2.1, U19.3 (Q0); also elsewhere on the board
/CLK: U19.7 (Cp); also elsewhere on the board
/~ALO: J10.2; also elsewhere on the board
GND: C19.2, C20.2, C21.2, C22.2, U16.7 (Vss), U17.7 (Vss), U18.3 (GND), U19.1 (Oe1), U19.2 (Oe2), U19.8 (GND), U19.15 (Mr); also elsewhere on the board
unnamed: J10.1, U19.9 (E1), U19.10 (E2)
unnamed: U16.1, U18.2
unnamed: U17.1, U18.1


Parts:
C3, C23, C24: 0.1uF; C_0603_1608Metric
U20, U21: 74AHC1G08; SOT-23-5
U22: 74LS157; SOIC-16_3.9x9.9mm_P1.27mm

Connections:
+5V: C3.1, C23.1, C24.1, U20.5 (VCC), U21.5 (VCC), U22.16 (VCC); also elsewhere on the board
/FLG_ZERO: U20.2; also elsewhere on the board
/JNZ: U20.1, U21.1, U22.1 (S); also elsewhere on the board
/PCEi: U22.14 (I0d); also elsewhere on the board
/jump logic/PCE: U22.12 (Zd); also elsewhere on the board
/jump logic/~PCL: U22.9 (Zc); also elsewhere on the board
/~PCLi: U22.11 (I0c); also elsewhere on the board
GND: C3.2, C23.2, C24.2, U20.3 (GND), U21.3 (GND), U22.8 (GND), U22.15 (E); also elsewhere on the board
unnamed: U20.4, U21.2, U22.10 (I1c)
unnamed: U21.4, U22.13 (I1d)


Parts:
J3: Conn_02x15_Odd_Even; IDC-Header_2x15_P2.54mm_Vertical

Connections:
+5V: J3.4; also elsewhere on the board
/ALU interface/BUS0: J3.7; also elsewhere on the board
/ALU interface/BUS1: J3.8; also elsewhere on the board
/ALU interface/BUS2: J3.10; also elsewhere on the board
/ALU interface/BUS3: J3.11; also elsewhere on the board
/ALU interface/BUS4: J3.13; also elsewhere on the board
/ALU interface/BUS5: J3.14; also elsewhere on the board
/ALU interface/BUS6: J3.16; also elsewhere on the board
/ALU interface/BUS7: J3.17; also elsewhere on the board
/ALU interface/BUS8: J3.19; also elsewhere on the board
/ALU interface/BUS9: J3.20; also elsewhere on the board
/ALU interface/BUS10: J3.22; also elsewhere on the board
/ALU interface/BUS11: J3.23; also elsewhere on the board
/ALU interface/BUS12: J3.25; also elsewhere on the board
/ALU interface/BUS13: J3.26; also elsewhere on the board
/ALU interface/BUS14: J3.28; also elsewhere on the board
/ALU interface/BUS15: J3.29; also elsewhere on the board
/CLK: J3.2; also elsewhere on the board
GND: J3.1, J3.3, J3.5, J3.6, J3.9, J3.12, J3.15, J3.18, J3.21, J3.24, J3.27, J3.30; also elsewhere on the board


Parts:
C13, C14, C15, C16, C17, C18: 0.1uF; C_0603_1608Metric
J5, J8: Conn_01x04; PinSocket_1x04_P2.54mm_Vertical
J7: Conn_01x02; PinHeader_1x02_P2.54mm_Vertical
U10: 74AHC1G08; SOT-23-5
U11: 74AHC1G04; SOT-23-5
U12, U14: 74AHC1G32; SOT-23-5
U13: 74AHC1G00; SOT-23-5
U15: 74HC173; SOIC-16_3.9x9.9mm_P1.27mm

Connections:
+5V: C13.1, C14.1, C15.1, C16.1, C17.1, C18.1, U10.3 (GND), U11.3 (GND), U12.5 (VCC), U13.5 (VCC), U14.5 (VCC), U15.16 (VCC); also elsewhere on the board
/ALU interface/FLG_CARRYo: U15.12 (D2); also elsewhere on the board
/ALU interface/FLG_SIGNo: U15.13 (D1); also elsewhere on the board
/ALU interface/FLG_ZEROo: U15.14 (D0); also elsewhere on the board
/CLK: U15.7 (Cp); also elsewhere on the board
/FLG_ZERO: J8.1, U15.3 (Q0); also elsewhere on the board
/register interface/FLG_GPU_READY: U15.11 (D3); also elsewhere on the board
/register interface/R0: J5.4, U10.1
/register interface/R1: J5.3, U10.2
/register interface/R2: J5.2, J7.1, U11.2, U13.2
/register interface/~FLOE: U14.4, U15.1 (Oe1), U15.2 (Oe2)
/register interface/~OE: J5.1, U14.1
/register interface/~SEL1: J7.2, U12.4
GND: C13.2, C14.2, C15.2, C16.2, C17.2, C18.2, U10.5 (VCC), U11.5 (VCC), U12.3 (GND), U13.3 (GND), U14.3 (GND), U15.8 (GND), U15.9 (E1), U15.10 (E2), U15.15 (Mr); also elsewhere on the board
unnamed: J8.2, U15.4 (Q1)
unnamed: J8.3, U15.5 (Q2)
unnamed: J8.4, U15.6 (Q3)
unnamed: U10.4, U12.2, U13.1
unnamed: U11.4, U12.1
unnamed: U13.4, U14.2


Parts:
C8, C9, C10, C11: 0.01uF; C_0603_1608Metric
C12: 0.1uF; C_0603_1608Metric
TP1: TestPoint; TestPoint_Pad_D1.0mm
U8: SN74AHCT16374DGGR; TSSOP-48_6.1x12.5mm_P0.5mm; Mouser Part Number 972-74FCT16374CTPVG
U9: 74AHC1G08; SOT-23-5

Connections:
+5V: C8.1, C9.1, C10.1, C11.1, C12.1, U8.7 (VCC_1), U8.18 (VCC_2), U8.31 (VCC), U8.42 (VCC_4), U9.5 (VCC); also elsewhere on the board
/ALU interface/BUS0: U8.47 (1D1); also elsewhere on the board
/ALU interface/BUS1: U8.46 (1D2); also elsewhere on the board
/ALU interface/BUS2: U8.44 (1D3); also elsewhere on the board
/ALU interface/BUS3: U8.43 (1D4); also elsewhere on the board
/ALU interface/BUS4: U8.41 (1D5); also elsewhere on the board
/ALU interface/BUS5: U8.40 (1D6); also elsewhere on the board
/ALU interface/BUS6: U8.38 (1D7); also elsewhere on the board
/ALU interface/BUS7: U8.37 (1D8); also elsewhere on the board
/ALU interface/BUS8: U8.36 (2D1); also elsewhere on the board
/ALU interface/BUS9: U8.35 (2D2); also elsewhere on the board
/ALU interface/BUS10: U8.33 (2D3); also elsewhere on the board
/ALU interface/BUS11: U8.32 (2D4); also elsewhere on the board
/ALU interface/BUS12: U8.30 (2D5); also elsewhere on the board
/ALU interface/BUS13: U8.29 (2D6); also elsewhere on the board
/ALU interface/BUS14: U8.27 (2D7); also elsewhere on the board
/ALU interface/BUS15: U8.26 (2D8); also elsewhere on the board
/CLK: U9.1; also elsewhere on the board
/reg16/DOUT0: U8.2 (1Q1); also elsewhere on the board
/reg16/DOUT1: U8.3 (1Q2); also elsewhere on the board
/reg16/DOUT2: U8.5 (1Q3); also elsewhere on the board
/reg16/DOUT3: U8.6 (1Q4); also elsewhere on the board
/reg16/DOUT4: U8.8 (1Q5); also elsewhere on the board
/reg16/DOUT5: U8.9 (1Q6); also elsewhere on the board
/reg16/DOUT6: U8.11 (1Q7); also elsewhere on the board
/reg16/DOUT7: U8.12 (1Q8); also elsewhere on the board
/reg16/DOUT8: U8.13 (2Q1); also elsewhere on the board
/reg16/DOUT9: U8.14 (2Q2); also elsewhere on the board
/reg16/DOUT10: U8.16 (2Q3); also elsewhere on the board
/reg16/DOUT11: U8.17 (2Q4); also elsewhere on the board
/reg16/DOUT12: U8.19 (2Q5); also elsewhere on the board
/reg16/DOUT13: U8.20 (2Q6); also elsewhere on the board
/reg16/DOUT14: U8.22 (2Q7)
/reg16/DOUT15: U8.23 (2Q8)
/reg16/WE: U9.2; also elsewhere on the board
GND: C8.2, C9.2, C10.2, C11.2, C12.2, U8.1 (1~OE), U8.4 (GND_1), U8.10 (GND_2), U8.15 (GND_3), U8.21 (GND_4), U8.24 (2~OE), U8.28 (GND), U8.34 (GND_6), U8.39 (GND_7), U8.45 (GND_8), U9.3 (GND); also elsewhere on the board
unnamed: TP1.1, U8.25 (2CLK), U8.48 (1CLK), U9.4



Board: 4 copper layers, 90.0 x 88.0 mm, 129 parts (25 on the bottom side), 133 nets.

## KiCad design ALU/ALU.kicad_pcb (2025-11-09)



Board: 4 copper layers, 100.0 x 100.0 mm, 82 parts (25 on the bottom side), 138 nets.

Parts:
C1, C6, C7, C8, C9, C10, C11, C12, C13, C14, C15, C16, C17, C18, C19, C20, C21, C22, C23, C24, C33, C34, C35: 0.1uF; C_0603_1608Metric
C2, C3, C4, C5, C25, C26, C27, C28, C29, C30, C31, C32: 0.01uF; C_0603_1608Metric
C36: 100uF; CP_Elec_5x5.3
D1: LED; LED_0603_1608Metric
H1, H2, H3, H4: MountingHole; MountingHole_4mm
IC1: SN74AHCT16245DGGR; TSSOP-48_6.1x12.5mm_P0.5mm
J1: Conn_01x06_Pin; PinHeader_1x06_P2.54mm_Vertical
J2, J3, J4: Conn_02x15_Odd_Even; IDC-Header_2x15_P2.54mm_Vertical
J5, J6, J7, J8: Conn_01x01_Pin; PinHeader_1x01_P2.54mm_Vertical
J9: Conn_01x02; PinHeader_1x02_P2.54mm_Vertical
R1: 1k; R_0603_1608Metric
R2: 100; R_0603_1608Metric
TP1, TP2, TP3, TP4, TP5, TP6, TP7, TP8: TestPoint; TestPoint_Pad_D1.0mm
U1, U17: 74AHC1G08; SOT-23-5
U2, U18: SN74AHCT16374DGGR; TSSOP-48_6.1x12.5mm_P0.5mm
U3: 74AHC1G04DBVR; SOT-23-5
U4, U5, U8, U9: 74LS181; DIP-24_W15.24mm_Socket
U6, U13, U14, U19: 74AHCT1G08DBVR; SOT-23-5
U7: 74HCT11; SOIC-14_3.9x8.7mm_P1.27mm
U10: 74HCT21; SOIC-14_3.9x8.7mm_P1.27mm
U11, U15, U16: 74AHC1G32DBVR; SOT-23-5
U12, U20, U21: 74AHCT1G02DBVR; SOT-23-5

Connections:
+5V: C1.1, C2.1, C3.1, C4.1, C5.1, C6.1, C7.1, C8.1, C9.1, C10.1, C11.1, C12.1, C13.1, C14.1, C15.1, C16.1, C17.1, C18.1, C19.1, C20.1, C21.1, C22.1, C23.1, C24.1, C25.1, C26.1, C27.1, C28.1, C29.1, C30.1, C31.1, C32.1, C33.1, C34.1, C35.1, C36.1, D1.2 (A), IC1.7 (VCC), IC1.18 (VCC), IC1.31 (VCC), IC1.42 (VCC), J2.4, J3.4, J9.2, R1.2, U1.5 (VCC), U2.7 (VCC_1), U2.18 (VCC_2), U2.31 (VCC), U2.42 (VCC_4), U3.5 (VCC), U4.24 (VCC), U5.24 (VCC), U6.5 (VCC), U7.14 (VCC), U8.24 (VCC), U9.24 (VCC), U10.14 (VCC), U11.5 (VCC), U12.5 (VCC), U13.5 (VCC), U14.5 (VCC), U15.5 (VCC), U16.5 (VCC), U17.5 (VCC), U18.7 (VCC_1), U18.18 (VCC_2), U18.31 (VCC), U18.42 (VCC_4), U19.5 (VCC), U20.5 (VCC), U21.5 (VCC)
/INA: J5.1, U17.2
/INA/DIN0: J2.7, U2.47 (1D1)
/INA/DIN1: J2.8, U2.46 (1D2)
/INA/DIN2: J2.10, U2.44 (1D3)
/INA/DIN3: J2.11, U2.43 (1D4)
/INA/DIN4: J2.13, U2.41 (1D5)
/INA/DIN5: J2.14, U2.40 (1D6)
/INA/DIN6: J2.16, U2.38 (1D7)
/INA/DIN7: J2.17, U2.37 (1D8)
/INA/DIN8: J2.19, U2.36 (2D1)
/INA/DIN9: J2.20, U2.35 (2D2)
/INA/DIN10: J2.22, U2.33 (2D3)
/INA/DIN11: J2.23, U2.32 (2D4)
/INA/DIN12: J2.25, U2.30 (2D5)
/INA/DIN13: J2.26, U2.29 (2D6)
/INA/DIN14: J2.28, U2.27 (2D7)
/INA/DIN15: J2.29, U2.26 (2D8)
/INA/DOUT0: U2.2 (1Q1), U4.2 (A0)
/INA/DOUT1: U2.3 (1Q2), U4.23 (A1)
/INA/DOUT2: U2.5 (1Q3), U4.21 (A2)
/INA/DOUT3: U2.6 (1Q4), U4.19 (A3)
/INA/DOUT4: U2.8 (1Q5), U8.2 (A0)
/INA/DOUT5: U2.9 (1Q6), U8.23 (A1)
/INA/DOUT6: U2.11 (1Q7), U8.21 (A2)
/INA/DOUT7: U2.12 (1Q8), U8.19 (A3)
/INA/DOUT8: U2.13 (2Q1), U5.2 (A0)
/INA/DOUT9: U2.14 (2Q2), U5.23 (A1)
/INA/DOUT10: U2.16 (2Q3), U5.21 (A2)
/INA/DOUT11: U2.17 (2Q4), U5.19 (A3)
/INA/DOUT12: U2.19 (2Q5), U9.2 (A0)
/INA/DOUT13: U2.20 (2Q6), U9.23 (A1)
/INA/DOUT14: U2.22 (2Q7), U9.21 (A2)
/INA/DOUT15: U2.23 (2Q8), U9.19 (A3)
/INB: J6.1, U1.2
/INB/DIN0: J3.7, U18.47 (1D1)
/INB/DIN1: J3.8, U18.46 (1D2)
/INB/DIN2: J3.10, U18.44 (1D3)
/INB/DIN3: J3.11, U18.43 (1D4)
/INB/DIN4: J3.13, U18.41 (1D5)
/INB/DIN5: J3.14, U18.40 (1D6)
/INB/DIN6: J3.16, U18.38 (1D7)
/INB/DIN7: J3.17, U18.37 (1D8)
/INB/DIN8: J3.19, U18.36 (2D1)
/INB/DIN9: J3.20, U18.35 (2D2)
/INB/DIN10: J3.22, U18.33 (2D3)
/INB/DIN11: J3.23, U18.32 (2D4)
/INB/DIN12: J3.25, U18.30 (2D5)
/INB/DIN13: J3.26, U18.29 (2D6)
/INB/DIN14: J3.28, U18.27 (2D7)
/INB/DIN15: J3.29, U18.26 (2D8)
/INB/DOUT0: U4.1 (B0), U18.2 (1Q1)
/INB/DOUT1: U4.22 (B1), U18.3 (1Q2)
/INB/DOUT2: U4.20 (B2), U18.5 (1Q3)
/INB/DOUT3: U4.18 (B3), U18.6 (1Q4)
/INB/DOUT4: U8.1 (B0), U18.8 (1Q5)
/INB/DOUT5: U8.22 (B1), U18.9 (1Q6)
/INB/DOUT6: U8.20 (B2), U18.11 (1Q7)
/INB/DOUT7: U8.18 (B3), U18.12 (1Q8)
/INB/DOUT8: U5.1 (B0), U18.13 (2Q1)
/INB/DOUT9: U5.22 (B1), U18.14 (2Q2)
/INB/DOUT10: U5.20 (B2), U18.16 (2Q3)
/INB/DOUT11: U5.18 (B3), U18.17 (2Q4)
/INB/DOUT12: U9.1 (B0), U18.19 (2Q5)
/INB/DOUT13: U9.22 (B1), U18.20 (2Q6)
/INB/DOUT14: U9.20 (B2), U18.22 (2Q7)
/INB/DOUT15: U9.18 (B3), U18.23 (2Q8)
/M: J1.1, U4.8 (M), U5.8 (M), U8.8 (M), U9.8 (M)
/S0: J1.3, U4.6 (S0), U5.6 (S0), U8.6 (S0), U9.6 (S0)
/S1: J1.4, U4.5 (S1), U5.5 (S1), U8.5 (S1), U9.5 (S1)
/S2: J1.5, U4.4 (S2), U5.4 (S2), U8.4 (S2), U9.4 (S2)
/S3: J1.6, U4.3 (S3), U5.3 (S3), U8.3 (S3), U9.3 (S3)
/Tri-State Buf16/A0: IC1.47 (A0), J4.7
/Tri-State Buf16/A1: IC1.46 (A1), J4.8
/Tri-State Buf16/A2: IC1.44 (A2), J4.10
/Tri-State Buf16/A3: IC1.43 (A3), J4.11
/Tri-State Buf16/A4: IC1.41 (A4), J4.13
/Tri-State Buf16/A5: IC1.40 (A5), J4.14
/Tri-State Buf16/A6: IC1.38 (A6), J4.16
/Tri-State Buf16/A7: IC1.37 (A7), J4.17
/Tri-State Buf16/A8: IC1.36 (A8), J4.19
/Tri-State Buf16/A9: IC1.35 (A9), J4.20
/Tri-State Buf16/A10: IC1.33 (A10), J4.22
/Tri-State Buf16/A11: IC1.32 (A11), J4.23
/Tri-State Buf16/A12: IC1.30 (A12), J4.25
/Tri-State Buf16/A13: IC1.29 (A13), J4.26
/Tri-State Buf16/A14: IC1.27 (A14), J4.28
/Tri-State Buf16/A15: IC1.26 (A15), J4.29
/Tri-State Buf16/B0: IC1.2 (B0), U4.9 (F0)
/Tri-State Buf16/B1: IC1.3 (B1), U4.10 (F1)
/Tri-State Buf16/B2: IC1.5 (B2), U4.11 (F2)
/Tri-State Buf16/B3: IC1.6 (B3), U4.13 (F3)
/Tri-State Buf16/B4: IC1.8 (B4), U8.9 (F0)
/Tri-State Buf16/B5: IC1.9 (B5), U8.10 (F1)
/Tri-State Buf16/B6: IC1.11 (B6), U8.11 (F2)
/Tri-State Buf16/B7: IC1.12 (B7), U8.13 (F3)
/Tri-State Buf16/B8: IC1.13 (B8), U5.9 (F0)
/Tri-State Buf16/B9: IC1.14 (B9), U5.10 (F1)
/Tri-State Buf16/B10: IC1.16 (B10), U5.11 (F2)
/Tri-State Buf16/B11: IC1.17 (B11), U5.13 (F3)
/Tri-State Buf16/B12: IC1.19 (B12), U9.9 (F0)
/Tri-State Buf16/B13: IC1.20 (B13), U9.10 (F1)
/Tri-State Buf16/B14: IC1.22 (B14), U9.11 (F2)
/Tri-State Buf16/B15: IC1.23 (B15), U9.13 (F3)
/Tri-State Buf16/~OE: IC1.25 (~OE2), IC1.48 (~OE1), J7.1, R1.1
/alu16/Cnx: TP7.1, U8.7 (Cn), U20.4
/alu16/Cny: TP3.1, U5.7 (Cn), U12.4
/alu16/Cnz: TP6.1, U9.7 (Cn), U21.4
/alu16/Cout: J8.1, U9.16 (Cn+4)
/alu16/X0: U4.15 (X), U7.3, U10.5, U19.2
/alu16/X1: U6.2, U7.9, U8.15 (X)
/alu16/X2: U5.15 (X), U14.2
/alu16/Y0: U4.17 (Y), U7.2, U7.4, U10.4, U10.10, U13.2, U19.1
/alu16/Y1: U6.1, U7.1, U7.5, U7.11, U8.17 (Y), U10.2, U10.12
/alu16/Y2: U5.17 (Y), U7.10, U10.1, U10.13, U14.1
/alu16/carry generator/Cin: U3.4, U7.13, U10.9, U13.1
/bus_connector2/CLK: J3.2, U1.1
/bus_connector/CLK: J2.2, U17.1
/~Cin: J1.2, U3.2, U4.7 (Cn)
GND: C1.2, C2.2, C3.2, C4.2, C5.2, C6.2, C7.2, C8.2, C9.2, C10.2, C11.2, C12.2, C13.2, C14.2, C15.2, C16.2, C17.2, C18.2, C19.2, C20.2, C21.2, C22.2, C23.2, C24.2, C25.2, C26.2, C27.2, C28.2, C29.2, C30.2, C31.2, C32.2, C33.2, C34.2, C35.2, C36.2, IC1.1 (T/~R1), IC1.4 (GND), IC1.10 (GND), IC1.15 (GND), IC1.21 (GND), IC1.24 (T/~R2), IC1.28 (GND), IC1.34 (GND), IC1.39 (GND), IC1.45 (GND), J2.1, J2.3, J2.5, J2.6, J2.9, J2.12, J2.15, J2.18, J2.21, J2.24, J2.27, J2.30, J3.1, J3.3, J3.5, J3.6, J3.9, J3.12, J3.15, J3.18, J3.21, J3.24, J3.27, J3.30, J4.1, J4.3, J4.5, J4.6, J4.9, J4.12, J4.15, J4.18, J4.21, J4.24, J4.27, J4.30, J9.1, R2.2, U1.3 (GND), U2.1 (1~OE), U2.4 (GND_1), U2.10 (GND_2), U2.15 (GND_3), U2.21 (GND_4), U2.24 (2~OE), U2.28 (GND), U2.34 (GND_6), U2.39 (GND_7), U2.45 (GND_8), U3.3 (GND), U4.12 (GND), U5.12 (GND), U6.3 (GND), U7.7 (GND), U8.12 (GND), U9.12 (GND), U10.7 (GND), U11.3 (GND), U12.3 (GND), U13.3 (GND), U14.3 (GND), U15.3 (GND), U16.3 (GND), U17.3 (GND), U18.1 (1~OE), U18.4 (GND_1), U18.10 (GND_2), U18.15 (GND_3), U18.21 (GND_4), U18.24 (2~OE), U18.28 (GND), U18.34 (GND_6), U18.39 (GND_7), U18.45 (GND_8), U19.3 (GND), U20.3 (GND), U21.3 (GND)
unnamed: D1.1 (K), R2.1
unnamed: TP1.1, U2.25 (2CLK), U2.48 (1CLK), U17.4
unnamed: TP4.1, U4.16 (Cn+4)
unnamed: TP5.1, U5.16 (Cn+4)
unnamed: TP8.1, U8.16 (Cn+4)
unnamed: U10.6, U16.2
unnamed: U10.8, U16.1
unnamed: U7.6, U11.1
unnamed: U6.4, U11.2
unnamed: U11.4, U12.2
unnamed: U7.12, U12.1
unnamed: U13.4, U20.1
unnamed: U14.4, U15.1
unnamed: U7.8, U15.2
unnamed: U15.4, U21.1
unnamed: U16.4, U21.2
unnamed: TP2.1, U1.4, U18.25 (2CLK), U18.48 (1CLK)
unnamed: U19.4, U20.2

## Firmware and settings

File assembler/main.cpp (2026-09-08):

#include <iostream>
#include <filesystem>
#include <instruction.h>
#include <parse.h>

#define MOV_LIKE {REG | REG_PTR | IMM_PTR, REG | REG_PTR | IMM_PTR | IMMEDIATE}
#define SINGLE_ARG {REG|REG_PTR|IMM_PTR}
#define SINGLE_ARG_ALL {REG | REG_PTR | IMM_PTR | IMMEDIATE}
#define NO_ARGS {}

void init_opcodes() {
    add_opcode("add", 0x0, MOV_LIKE);
    add_opcode("sub", 0x1, MOV_LIKE);
    add_opcode("and", 0x2, MOV_LIKE);
    add_opcode("nand", 0x3, MOV_LIKE);
    add_opcode("or", 0x4, MOV_LIKE);
    add_opcode("nor", 0x5, MOV_LIKE);
    add_opcode("xor", 0x6, MOV_LIKE);
    add_opcode("neg", 0x7, SINGLE_ARG);
    add_opcode("not", 0x8, SINGLE_ARG);
    add_opcode("shl", 0x9, SINGLE_ARG);
    add_opcode("inc", 0xa, SINGLE_ARG);
    add_opcode("dec", 0xb, SINGLE_ARG);
    add_opcode("cmp", 0xc, MOV_LIKE);
    add_opcode("mov", 0xd, MOV_LIKE);
//    add_opcode("movr", 0xe, MOV_LIKE);
    add_opcode("push", 0xf, SINGLE_ARG_ALL);
    add_opcode("pop", 0x10, SINGLE_ARG);
    add_opcode("swp", 0x11, NO_ARGS);
    add_opcode("jmp", 0x12, {REG | IMMEDIATE});
    add_opcode("jnz", 0x13, {REG | IMMEDIATE});
    add_opcode("call", 0x19, {REG | IMMEDIATE});
    add_opcode("ret", 0x1a, NO_ARGS);
}

static void usage(const char *prog) {
    std::cerr << "Usage: " << prog << " <input.S> [-o <output>]\n";
}

int main(int argc, char *argv[]) {
    if (argc < 2) {
        usage(argv[0]);
        return 1;
    }

    std::string input_file;
    std::string output_file;

    for (int i = 1; i < argc; i++) {
        std::string arg = argv[i];
        if (arg == "-o") {
            if (i + 1 >= argc) {
                std::cerr << "Error: -o requires an argument\n";
                return 1;
            }
            output_file = argv[++i];
        } else if (arg == "-h" || arg == "--help") {
            usage(argv[0]);
            return 0;
        } else if (arg[0] == '-') {
            std::cerr << "Error: unknown flag '" << arg << "'\n";
            usage(argv[0]);
            return 1;
        } else {
            if (!input_file.empty()) {
                std::cerr << "Error: multiple input files specified\n";
                usage(argv[0]);
                return 1;
            }
            input_file = arg;
        }
    }

    if (output_file.empty()) {
        output_file = std::filesystem::path(input_file).stem().string() + ".o";
    }

    init_opcodes();
    add_register("ax", 0x0);
    add_register("bx", 0x1);
    add_register("cx", 0x2);
    add_register("dx", 0x3);
    add_register("ex", 0x4);
    add_register("fx", 0x5);
    add_register("sp", 0x6);
    add_register("fl", 0x7);

    Parser parser_engine(input_file);
    parser_engine.parse();
    parser_engine.write_machine_code(output_file);

    return 0;
}

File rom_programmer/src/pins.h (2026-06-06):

#ifndef PINS_H
#define PINS_H

// ---------------------------------------------------------------------------
// 74HC595 shift register chain — drives flash address bits A0–A14
// Two cascaded 595s: first shiftOut byte → downstream reg (A8–A14),
//                   second shiftOut byte → upstream reg  (A0–A7)
// ---------------------------------------------------------------------------
#define LATCH_PIN  8
#define CLK_PIN    12
#define DATA_PIN   11

// ---------------------------------------------------------------------------
// Upper address bits driven directly from Arduino digital pins.
//
// Flash address bit mapping (see write_address() in flash.cpp):
//
//   Arduino pin │ flash pin │ macro  │ used by
//   ────────────┼───────────┼────────┼──────────────────────
//   A3          │ A15       │ ADDR15 │ 010A, 020A, 040
//   4           │ A16       │ ADDR16 │ 010A (AMS), 020A, 040
//   A5          │ A17       │ ADDR17 │ 020A (AMS), 040
//   13          │ A18       │ ADDR18 │ 040  (AMS)
//
// On SST39SF010A pin A17 is NC, on SST39SF020A pin A18 is NC — the firmware
// drives those pins anyway; the chip simply ignores them.
//
// WARNING: A6 and A7 are analog-input-only on Uno/Nano.
//          Do NOT reassign ADDR18/ADDR19 to those pins.
// ---------------------------------------------------------------------------
#define ADDR16  A3    // flash A16  — 010A (AMS) / 020A / 040
#define ADDR17  A4   // flash A17  — 020A (AMS) / 040   (NC on 010A)
#define ADDR18  A5   // flash A18  — 040  (AMS)          (NC on 010A/020A)

// ---------------------------------------------------------------------------
// Flash control lines
// ---------------------------------------------------------------------------
#define nCE  7      // Chip Enable   (active low)
#define nOE  9       // Output Enable (active low)
#define nWE  10       // Write Enable  (active low)

#endif //PINS_H

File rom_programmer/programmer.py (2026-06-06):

#!/usr/bin/env python3
"""
programmer.py
-------------
Programs an SST39SF010A/020A/040 flash chip via an Arduino running the
companion firmware.

Usage
-----
    python programmer.py COM3 image.hex                  # write + verify
    python programmer.py /dev/ttyUSB0 image.hex --no-verify
    python programmer.py COM3 image.hex --sector-erase   # erase only used sectors
    python programmer.py COM3 --identify                 # print chip IDs and exit
    python programmer.py COM3 --chip-erase               # blank the chip and exit

Dependencies
------------
    pip install pyserial
"""

import argparse
import sys
import time
import struct
from typing import Optional

import serial

from logisim_parser import load as load_hex

# ---------------------------------------------------------------------------
# Protocol constants — must match protocol.h in the firmware
# ---------------------------------------------------------------------------
CMD_PING          = b'P'
CMD_GET_ID        = b'I'
CMD_CHIP_ERASE    = b'E'
CMD_SECTOR_ERASE  = b'S'
CMD_WRITE         = b'W'
CMD_READ          = b'R'

RESP_OK    = ord('K')
RESP_ERR   = ord('F')
RESP_READY = ord('Z')

SECTOR_SIZE  = 0x1000          # 4 KB per datasheet
CHUNK_SIZE   = 64              # bytes per write/read command
BAUD_RATE    = 230400
BOOT_TIMEOUT = 5.0             # seconds to wait for RESP_READY after reset

# ---------------------------------------------------------------------------
# Known device IDs → (description, chip_size_in_bytes)
# ---------------------------------------------------------------------------
DEVICE_IDS: dict[tuple[int, int], tuple[str, int]] = {
    (0xBF, 0xB5): ("SST39SF010A (1 Mbit, 128 KB)", 0x010000),
    (0xBF, 0xB6): ("SST39SF020A (2 Mbit, 256 KB)", 0x020000),
    (0xBF, 0xB7): ("SST39SF040  (4 Mbit, 512 KB)", 0x040000),
}


# ---------------------------------------------------------------------------
# Programmer class
# ---------------------------------------------------------------------------

class ProtocolError(Exception):
    pass


class Programmer:
    def __init__(self, port: str, baud: int = BAUD_RATE):
        self._ser = serial.Serial(port, baud, timeout=10)
        self._wait_for_ready()

    def close(self):
        self._ser.close()

    # ------------------------------------------------------------------
    # Connection
    # ------------------------------------------------------------------

    def _wait_for_ready(self):
        """Block until the Arduino sends RESP_READY or the timeout expires."""
        print("Waiting for Arduino...", end="", flush=True)
        self._ser.timeout = 0.1
        deadline = time.monotonic() + BOOT_TIMEOUT
        buf = b""
        while time.monotonic() < deadline:
            buf += self._ser.read(64)
            if RESP_READY in buf:
                print(" ready.")
                self._ser.timeout = 10
                self._ser.reset_input_buffer()
                return
        # Arduino may not have reset (no DTR line); try a ping instead
        self._ser.timeout = 2
        self._ser.reset_input_buffer()
        self._ser.write(CMD_PING)
        resp = self._ser.read(1)
        if resp and resp[0] == RESP_OK:
            print(" connected (no reset detected).")
            return
        raise TimeoutError(
            "Arduino did not respond.  Check port, baud rate, and that the "
            "correct firmware is uploaded."
        )

    # ------------------------------------------------------------------
    # Internal helpers
    # ------------------------------------------------------------------

    def _recv(self, n: int) -> bytes:
        data = self._ser.read(n)
        if len(data) != n:
            raise TimeoutError(f"Expected {n} bytes, got {len(data)}")
        return data

    def _expect_ok(self):
        resp = self._recv(1)[0]
        if resp != RESP_OK:
            raise ProtocolError(f"Expected OK (0x{RESP_OK:02X}), got 0x{resp:02X}")

    @staticmethod
    def _addr_bytes(address: int) -> bytes:
        """Pack a 24-bit address as 3 big-endian bytes."""
        return struct.pack(">I", address)[1:]   # drop the high byte of a 32-bit int

    # ------------------------------------------------------------------
    # Public API
    # ------------------------------------------------------------------

    def ping(self):
        self._ser.write(CMD_PING)
        self._expect_ok()

    def get_id(self) -> tuple[int, int]:
        """Return (manufacturer_id, device_id)."""
        self._ser.write(CMD_GET_ID)
        self._expect_ok()
        data = self._recv(2)
        return data[0], data[1]

    def chip_erase(self):
        """Erase the entire chip.  Blocks until complete (~100 ms)."""
        self._ser.timeout = 5
        self._ser.write(CMD_CHIP_ERASE)
        self._expect_ok()
        self._ser.timeout = 10

    def sector_erase(self, address: int):
        """Erase the 4 KB sector containing *address*."""
        self._ser.timeout = 2
        self._ser.write(CMD_SECTOR_ERASE + self._addr_bytes(address))
        self._expect_ok()
        self._ser.timeout = 10

    def write_chunk(self, address: int, data: bytes | bytearray):
        """Write up to 256 bytes.  The target area must already be erased."""
        assert 1 <= len(data) <= 256, "Chunk must be 1–256 bytes"
        # len=0 on the wire encodes 256
        wire_len = len(data) & 0xFF
        self._ser.write(CMD_WRITE + self._addr_bytes(address) + bytes([wire_len]) + bytes(data))
        self._expect_ok()

    def read_chunk(self, address: int, length: int) -> bytes:
        """Read *length* bytes (1–65535) from the chip."""
        assert 1 <= length <= 0xFFFF
        self._ser.write(CMD_READ + self._addr_bytes(address) + struct.pack(">H", length))
        data = self._recv(length)
        self._expect_ok()
        return data

    # ------------------------------------------------------------------
    # High-level operations
    # ------------------------------------------------------------------

    def erase_sectors_for(self, image: bytearray):
        """Erase only the sectors that contain non-0xFF data."""
        sectors = sorted({
            addr // SECTOR_SIZE
            for addr, byte in enumerate(image)
            if byte != 0xFF
        })
        if not sectors:
            print("Image is all 0xFF — nothing to erase.")
            return
        print(f"Erasing {len(sectors)} sector(s)...")
        for i, sector in enumerate(sectors):
            base = sector * SECTOR_SIZE
            self.sector_erase(base)
            _progress(i + 1, len(sectors), prefix="  Erase")
        print()

    def program(self, image: bytearray):
        """Write *image* to the chip, skipping all-0xFF chunks."""
        total   = len(image)
        written = 0
        addr    = 0
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

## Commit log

2025-02-15 Setup comms between arduino and host
2025-02-20 cleaned up KiCad temporary files
    [AOS16 Double Buffer-B_Cu.gbl, AOS16 Double Buffer-B_Mask.gbs, AOS16 Double Buffer-B_Paste.gbp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]
2025-02-21 reduced buffer size to comply with arduino serial buffer
2025-02-21 updated double buffer
    [AOS16 Double Buffer(1).kicad_sch, AOS16 Double Buffer-test.kicad_sch, AOS16 Double Buffer.kicad_pcb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]
2025-02-26 Added Logisim schematic
    [ALU.kicad_pcb, ALU.kicad_sch, AOS16 Double Buffer.kicad_pcb]
2025-03-02 Completed double buffer first draft
    [AOS16 Double Buffer.kicad_pcb, AOS16 Double Buffer.kicad_sch, PSU.kicad_pcb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]
2025-03-02 Finalized double buffer
    [AOS16 Double Buffer.kicad_pcb]
2025-03-04 Added base Logisim schematic and microcode
2025-03-05 Added ALU function mapping and reg to reg mov instruction
    [Memory.kicad_pcb, Memory.kicad_sch, bus_connector.kicad_sch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]
2025-03-07 Began working on assembler
2025-03-07 created basic assembly parser
2025-03-08 Added machine code output and misc fixes
    [main.cpp]
2025-03-08 completed assembler framework
2025-03-09 fixed uint8 and uint16 directives
    [main.cpp]
2025-03-22 Double Buffer Revision
    [AOS16 Double Buffer.kicad_pcb, AOS16 Double Buffer.kicad_sch, pull_resistor.kicad_sch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]
2025-03-22 Completed ALU first draft
    [ALU.kicad_pcb, ALU.kicad_sch, alu16.kicad_sch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]
2025-03-31 Updated ALU and moved common schematics to common/ for enhanced reusability
    [ALU.kicad_pcb, ALU.kicad_sch, alu16.kicad_sch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]
2025-03-31 Fixed double buffer logic families
    [AOS16 Double Buffer.kicad_pcb, AOS16 Double Buffer.kicad_sch, ram_chip.kicad_sch]
2025-04-02 Fixed tri-state buffer and completed double buffer PCB
    [ALU.kicad_pcb, AOS16 Double Buffer.kicad_pcb, AOS16 Double Buffer.kicad_sch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]
2025-04-02 Fixed ERC errors
    [ALU.kicad_pcb, AOS16 Double Buffer.kicad_pcb]
2025-04-03 Made tri-state and register schematic look nice
    [reg16F.kicad_sch, tri-state buffer16.kicad_sch]
2025-04-03 Fixed ALU silkscreen for new fab
    [ALU.kicad_pcb, carry generator.kicad_sch]
2025-04-03 Fixed silkscreen on ALU and Double Buffer
    [ALU.kicad_pcb, ALU.kicad_sch, AOS16 Double Buffer.kicad_pcb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]
2025-05-27 Started GPU
    [ALU.kicad_pcb, AOS16 GPU.kicad_pcb, AOS16 GPU.kicad_sch]
2025-05-27 Added horizontal counting circuit
    [AOS16 GPU.kicad_sch, hcounter.kicad_sch]
2025-06-01 Completed GPU schematic
    [5bitdac.kicad_sch, AOS16 GPU.kicad_sch, vcounter.kicad_sch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]
2025-06-05 Migrated to KiCad 9.0 and made changes to GPU
    [AOS16 Double Buffer.kicad_pcb, AOS16 GPU.kicad_pcb, hcounter.kicad_sch]
2025-06-16 Fixed incorrect wiring in ALU (input registers)
    [ALU.kicad_pcb, ALU.kicad_sch, bus_conn.kicad_sch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]
2025-06-22 Fixed ALU error
    [ALU.kicad_pcb, alu16.kicad_sch, carry generator.kicad_sch]
2025-06-22 Changed register in logisim circuit
2025-06-23 Assembler fix- removed extra zeros
    [main.cpp]
2025-06-23 Fixed wiring error
2025-06-23 Completed reg4x16
    [reg4x16.kicad_pcb, reg4x16.kicad_sch]
2025-07-06 Added negative constants to assembler
2025-09-03 Fixed register data flow direction and added mounitng holes to ALU
    [ALU.kicad_pcb, ALU.kicad_sch, reg16F.kicad_sch]
2025-09-04 Added arduino test for 74HC670
2025-09-04 Refactored files, finalized reg4x16, and used lowercase v
    [ALU.kicad_pcb, AOS16 Memory.kicad_pcb, AOS16 Memory.kicad_sch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]
2025-09-08 Memory Controller- Initial setup
    [AOS16 Double Buffer.kicad_sch, Memory Controller-copy.kicad_pcb, Memory Controller.kicad_pcb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]
2025-09-13 Memory Controller first draft
    [Memory Controller.kicad_pcb, Memory Controller.kicad_sch, rom.kicad_sch]
2025-10-10 Software update: firmware update, assembler fixes and sim fixes for a fibonacci sequence program
    [main.cpp]
2025-10-22 Control Unit first draft
    [Control.kicad_pcb, Control.kicad_sch]
2025-11-09 Memory Controller fabrication checks complete
    [ALU.kicad_pcb, ALU.kicad_sch, Memory Controller.kicad_pcb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]
2025-12-17 Cleanup, added photos and README overhaul
    [Control.kicad_pcb, Control.kicad_sch, aluinterface.kicad_sch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]
2026-01-18 Finalized Control unit for fabrication
    [Control.kicad_pcb, Control.kicad_sch, aluinterface.kicad_sch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]
2026-03-11 Updated control unit and finalized for fabrication
    [Control.kicad_pcb, Control.kicad_sch, aluinterface.kicad_sch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]
2026-03-29 Added clock circuit schematic
    [clock.kicad_pcb, clock.kicad_sch]
2026-04-11 Finalized clock for fabrication
    [clock.kicad_pcb, clock.kicad_sch]
2026-04-12 Overhauled program counter schematic
    [Program Counter.kicad_pcb, Program Counter.kicad_sch, bus_conn.kicad_sch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]
2026-05-28 GPU PCB Design v1
    [AOS16 GPU.kicad_pcb, AOS16 GPU.kicad_sch, hcounter.kicad_sch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]
2026-05-31 Added bus connector
    [Bus Connector.kicad_pcb, Bus Connector.kicad_sch]
2026-06-05 Updated sim schematic GPU to match new arch
2026-06-13 updated gpu
    [5bitdac.kicad_sch, AOS16 GPU.kicad_pcb, AOS16 GPU.kicad_sch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]
2026-06-13 added bus boards, bus probe, bus terminator and distribution board
    [Bus Connector.kicad_pcb, Bus Probe.kicad_pcb, Bus Probe.kicad_sch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]
2026-06-13 Added program counter PCB
    [Program Counter.kicad_pcb, Program Counter.kicad_sch]
2026-06-14 Updated silkscreen and cascade wiring program counter
    [Program Counter.kicad_pcb, Program Counter.kicad_sch]
2026-06-29 assembler bug fixes
2026-06-29 added macros to assembler
2026-09-08 assembler, fixed filename mismatch and msvc-specific directives
    [main.cpp]
2026-11-12 ALU KiCAD version migration
2026-11-12 Bus connector migration and updates
